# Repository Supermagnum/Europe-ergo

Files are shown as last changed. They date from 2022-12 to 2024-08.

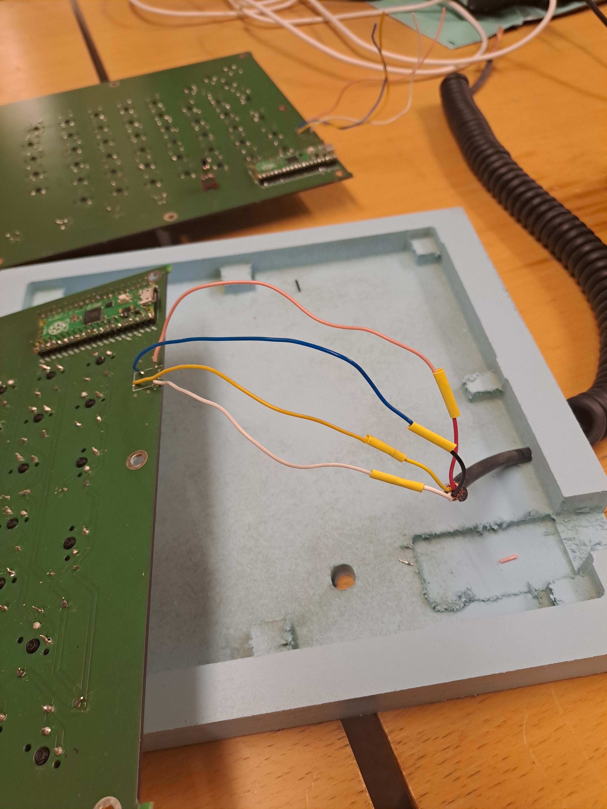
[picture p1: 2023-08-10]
prototype-build/20230810_170116.jpg

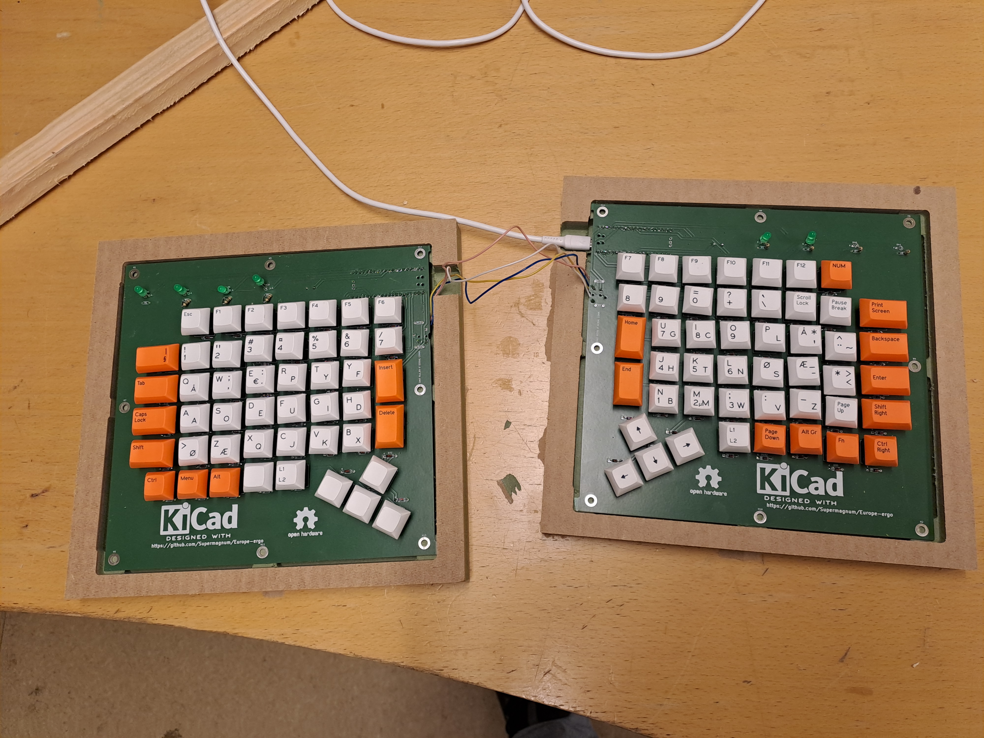
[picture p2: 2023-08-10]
prototype-build/20230720_191944.jpg

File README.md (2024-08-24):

# Europe-ergo
A 94 key ergonomic,split keyboard.
Its powered by 2X Raspberry pico and linked with two 5 pin D sub connectors.
It uses tht components.

The reset switches, 5 pin D sub connectors and raspberry pico's  goes on the reverse side of the Pcb's. 

Picture of Pcb's top side:
https://github.com/Supermagnum/Europe-ergo/blob/main/Europe-ergo-PCB/Europe-ergo-frontside.jpg

Backside:
https://github.com/Supermagnum/Europe-ergo/blob/main/Europe-ergo-PCB/Europe-ergo-backside.jpg

Layout:
https://github.com/Supermagnum/Europe-ergo/blob/main/layout.png

or:

http://www.keyboard-layout-editor.com/#/gists/50db7ea7b0832342d4c734eb985ec16b

The L1/L2 button is to change from  Norwegian QWERTY to Norwegian Dvorak.
There are relevant LEDs that lights up depending on what layer is active.

The NUM key can be used to turn the  num layer on or off.

Keycaps:
https://github.com/Supermagnum/Europe-ergo/blob/main/keycaps.jpg

prototype/"proof of concept" build pictures:
https://github.com/Supermagnum/Europe-ergo/tree/main/prototype-build

Electronic diagram:
https://github.com/Supermagnum/Europe-ergo/blob/main/Europe-ergo-PCB/schema/Europe-ergo.pdf

All mechanical blueprints as pdf files can be exported from the Freecad file.
Freecad can be found for free here:
https://www.freecadweb.org/

PWM1 to PWM 5 controls LED's ( ON/OFF) based by the active layer, and also caps lock and scroll lock active.

Those and the electrical diagram can be found here:
https://github.com/Supermagnum/Europe-ergo/blob/main/Europe-ergo-PCB/schema/Europe-ergo.pdf
The right side has identical outputs for PWM.

Cherry MX switches fit the PCB'S.

Missing from the BOM:
Keyswitch Hotswap sockets: 0305-2-15-80-47-80-10-0 or Digikey: ED90584-ND

STL files for 3D printing or milling of the boxes:
https://github.com/Supermagnum/Europe-ergo/tree/main/mechanical

Tool for aligning the switches under soldering, slips on to the PCB edge an over the switch:
https://github.com/Supermagnum/Europe-ergo/blob/main/mechanical/STL/switch-tool.stl

Panelized version:
https://github.com/Supermagnum/erope-ergo-ex

License:
https://github.com/Supermagnum/Europe-ergo/blob/main/LICENSE

 "

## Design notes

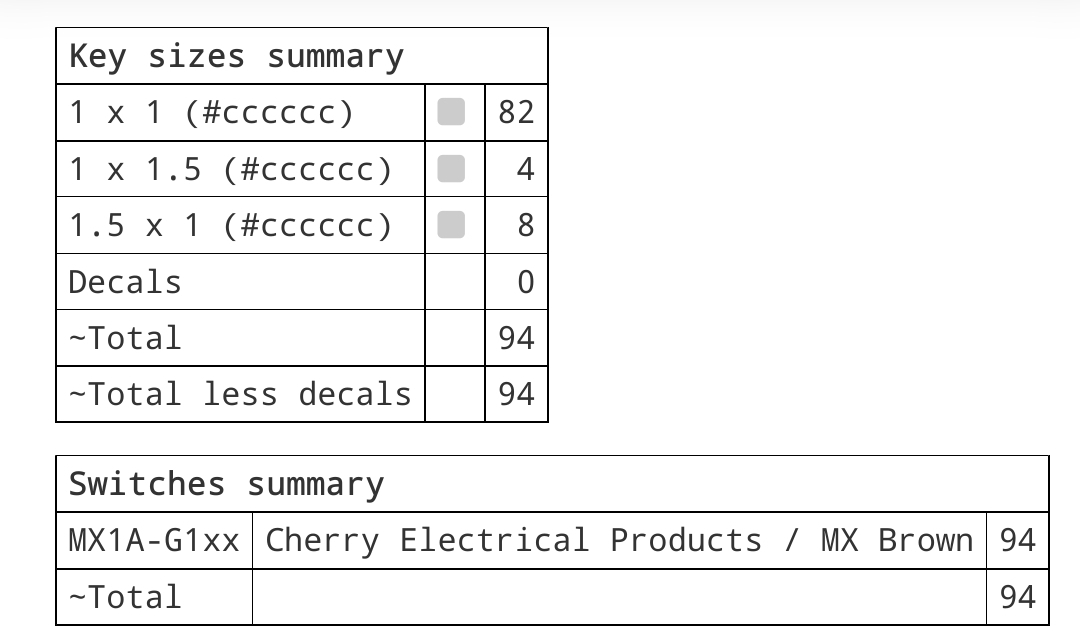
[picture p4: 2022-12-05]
keycaps.jpg

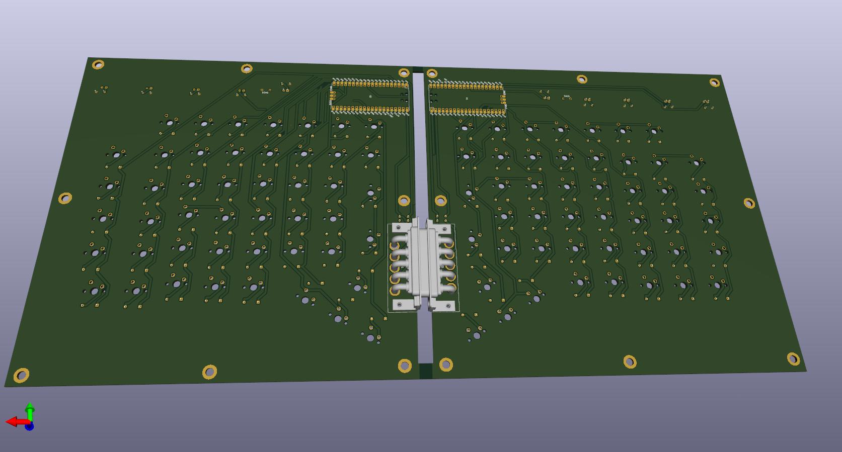
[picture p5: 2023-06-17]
Europe-ergo-PCB/Europe-ergo-backside.jpg

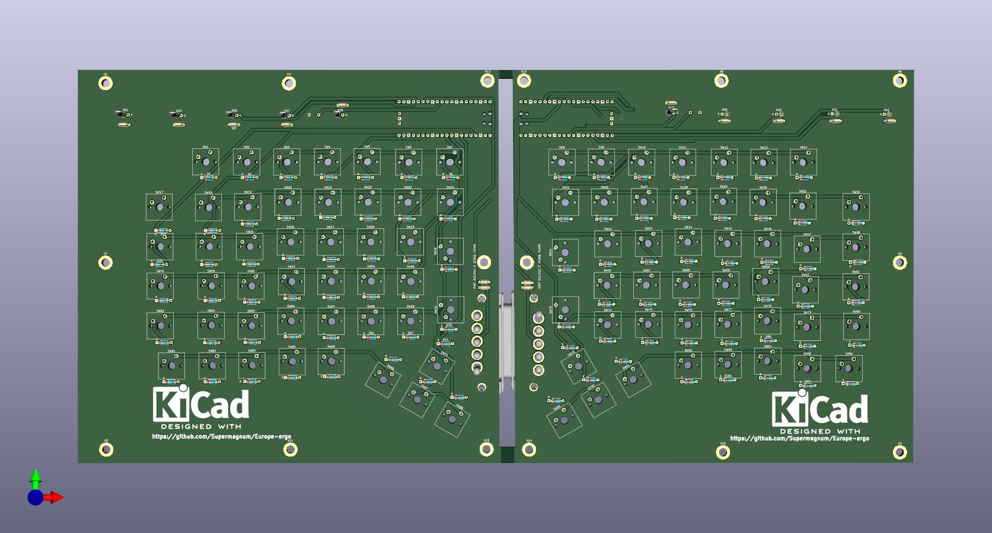
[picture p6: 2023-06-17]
Europe-ergo-PCB/Europe-ergo-frontside.jpg

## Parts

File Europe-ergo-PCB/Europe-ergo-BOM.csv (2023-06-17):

Source: | /mnt/b955457f-512b-4f44-a0f7-8e5f2b78aba2/Europe-ergo/Europe-ergo-PCB/Europe-ergo.kicad_sch
Date: | fr. 31. mars 2023 kl. 15.45 +0200
Tool: | Eeschema 7.0.1-3b83917a11~172~ubuntu22.04.1
Generator: | /usr/share/kicad/plugins/bom_csv_grouped_by_value.py
Component Count: | 234
Collated Components:
Item | Qty | Reference(s) | Value | LibPart | Footprint | Datasheet | DNP | Field4
1 | 94 | D1, D2, D3, D4, D5, D6, D7, D8, D9, D10, D11, D12, D13, D14, D15, D16, D17, D18, D19, D20, D21, D22, D23, D24, D25, D26, D27, D28, D29, D30, D33, D34, D35, D44, D45, D46, D47, D48, D49, D50, D51, D52, D53, D54, D55, D56, D57, D58, D59, D60, D61, D62, D63, D64, D65, D66, D67, D68, D69, D70, D71, D72, D73, D74, D75, D76, D77, D78, D79, D80, D81, D82, D83, D84, D85, D86, D87, D88, D89, D90, D91, D92, D93, D94, D95, D96, D97, D98, D99, D100, D101, D102, D103, D104 | 1N4148 | Diode:1N4148 | Diode_THT:D_DO-35_SOD27_P7.62mm_Horizontal | https://assets.nexperia.com/documents/data-sheet/1N4148_1N4448.pdf
2 | 6 | D31, D32, D36, D37, D38, D43 | LTL-4233 | Device:LED | Diode_THT:D_A-405_P2.54mm_Vertical_AnodeUp | ~
3 | 4 | D39, D40, D41, D42 | LTL-4233 | Device:LED | Diode_THT:D_DO-34_SOD68_P2.54mm_Vertical_KathodeUp | ~
4 | 16 | H1, H2, H3, H4, H5, H6, H7, H8, H9, H10, H11, H12, H13, H14, H15, H16 | MountingHole_Pad | Mechanical:MountingHole_Pad | MountingHole:MountingHole_4.3mm_M4_DIN965_Pad | ~
5 | 2 | J1, J2 | SJ-435107 | Connector: CONN D-SUB PLUG 5POS R/A SLDR | NOR1213-ND | ~
6 | 10 | R1, R2, R3, R4, R5, R6, R7, R8, R9, R10 | 330 | Device:R | Resistor_THT:R_Axial_DIN0204_L3.6mm_D1.6mm_P5.08mm_Horizontal | ~
7 | 4 | R11, R12, R13, R14 | 4.7K | Device:R | Resistor_THT:R_Axial_DIN0204_L3.6mm_D1.6mm_P5.08mm_Horizontal | ~
8 | 41 | SW1, SW2, SW3, SW4, SW5, SW6, SW7, SW18, SW19, SW20, SW21, SW22, SW23, SW24, SW34, SW35, SW36, SW37, SW38, SW39, SW50, SW51, SW52, SW53, SW54, SW55, SW64, SW65, SW66, SW67, SW68, SW69, SW71, SW81, SW82, SW83, SW84, SW85, SW86, SW87, SW88 | MX1A-G1NN | pcb-flat-left-rescue:MX-NO-LED-keyboard2-pcb-flat-right-rescue | Button_Switch_Keyboard:SW_Cherry_MX_1.00u_PCB |  |  | arrow-up
9 | 41 | SW8, SW9, SW10, SW11, SW12, SW13, SW14, SW25, SW26, SW27, SW28, SW29, SW30, SW31, SW42, SW43, SW44, SW45, SW46, SW47, SW56, SW57, SW58, SW59, SW60, SW61, SW72, SW74, SW75, SW76, SW77, SW78, SW79, SW89, SW90, SW91, SW92, SW93, SW94, SW95, SW96 | MX1A-G1NN | pcb-flat-right-rescue:MX-NO-LED-keyboard2 | Button_Switch_Keyboard:SW_Cherry_MX_1.00u_PCB |  |  | arrow-up
10 | 2 | SW15, SW16 | 800SP9B6M2RE | Switch:SW_Push | switch:switch_P5.08mm | ~
11 | 6 | SW17, SW33, SW40, SW49, SW63, SW70 | MX1A-G1NN | pcb-flat-left-rescue:MX-NO-LED-keyboard2-pcb-flat-right-rescue | Button_Switch_Keyboard:SW_Cherry_MX_1.50u_PCB
12 | 6 | SW32, SW41, SW48, SW62, SW73, SW80 | MX1A-G1NN | pcb-flat-right-rescue:MX-NO-LED-keyboard2 | Button_Switch_Keyboard:SW_Cherry_MX_1.50u_PCB
13 | 2 | U1, U2 | SC0915 | MCU_RaspberryPi_and_Boards:Pico | MCU_RaspberryPi_and_Boards:RPi_Pico_SMD_TH

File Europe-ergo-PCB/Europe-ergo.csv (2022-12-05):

Source: | /home/haaken/98keys-ergo.git/trunk/98keys-split-pcb/98keys-split-pcb.kicad_sch
Date: | lø. 03. des. 2022 kl. 18.18 +0100
Tool: | Eeschema 6.0.9-8da3e8f707~117~ubuntu20.04.1
Generator: | /usr/share/kicad/plugins/bom_csv_grouped_by_value_with_fp.py
Component Count: | 230
Ref | Qnty | Value | Cmp name | Footprint | Description | Vendor
D1, D2, D3, D4, D5, D6, D7, D8, D9, D10, D11, D12, D13, D14, D15, D16, D17, D18, D19, D20, D21, D22, D23, D24, D25, D26, D27, D28, D29, D30, D31, D32, D33, D34, D35, D36, D37, D38, D39, D40, D41, D42, D43, D44, D45, D46, D47, D56, D57, D58, D59, D60, D61, D62, D63, D64, D65, D66, D67, D68, D69, D70, D71, D72, D73, D74, D75, D76, D77, D78, D79, D80, D81, D82, D83, D84, D85, D86, D87, D88, D89, D90, D91, D92, D93, D94, D95, D96, D97, D98, D99, D100, D101, D102, | 94 | 1N4148 | 1N4148 | Diode_THT:D_DO-35_SOD27_P7.62mm_Horizontal | 100V 0.15A standard switching diode, DO-35
D48, D49, D50, D51, | 4 | LED | LED | Diode_THT:D_DO-34_SOD68_P2.54mm_Vertical_KathodeUp | Light emitting diode
D52, D53, D54, D55, | 4 | LTL-4233 | LED | Diode_THT:D_A-405_P2.54mm_Vertical_AnodeUp | Light emitting diode
H1, H2, H3, H4, H5, H6, H7, H8, H9, H10, H11, H12, H13, H14, H15, H16, | 16 | MountingHole_Pad | MountingHole_Pad | MountingHole:MountingHole_4.3mm_M4_DIN965_Pad | Mounting Hole with connection
J1, | 1 | Conn_01x04_Male/I2C | Conn_01x04_Male | Connector_Audio:Jack_3.5mm_CUI_SJ1-43514_Horizontal | Generic connector, single row, 01x04, script generated (kicad-library-utils/schlib/autogen/connector/)
J2, | 1 | Conn_01x04_Male | Conn_01x04_Male | Connector_Audio:Jack_3.5mm_CUI_SJ1-43514_Horizontal | Generic connector, single row, 01x04, script generated (kicad-library-utils/schlib/autogen/connector/)
R1, R2, R4, R6, R7, R8, R10, R12, | 8 | 330 | R | Resistor_THT:R_Axial_DIN0204_L3.6mm_D1.6mm_P5.08mm_Horizontal | Resistor
R3, R5, R9, R11, | 4 | 4.7K | R | Resistor_THT:R_Axial_DIN0204_L3.6mm_D1.6mm_P5.08mm_Horizontal | Resistor
SW1, SW6, SW7, SW8, SW9, SW10, SW11, SW12, SW13, SW14, SW15, SW16, SW17, SW18, SW19, SW20, SW21, SW22, SW23, SW24, SW25, SW26, SW27, SW28, SW29, SW30, SW31, SW32, SW33, SW34, SW35, SW36, SW37, SW38, SW39, SW40, SW41, SW42, SW45, SW46, SW47, SW50, SW51, SW52, SW55, SW56, SW57, SW58, SW59, SW60, SW61, SW62, SW63, SW64, SW65, SW66, SW67, SW68, SW69, SW70, SW71, SW72, SW73, SW74, SW75, SW76, SW77, SW78, SW79, SW80, SW81, SW82, SW83, SW84, SW85, SW86, SW87, SW88, SW89, SW90, SW92, SW96, | 82 | MX-NO-LED | MX-NO-LED-keyboard2-pcb-flat-right-rescue | Button_Switch_Keyboard:SW_Cherry_MX_1.00u_PCB
SW2, SW3, SW4, SW5, SW43, SW44, SW53, SW54, SW91, SW93, SW94, SW95, | 12 | MX-NO-LED | MX-NO-LED-keyboard2-pcb-flat-right-rescue | Button_Switch_Keyboard:SW_Cherry_MX_1.50u_PCB
SW48, SW49, | 2 | SW_Push | SW_Push | switch:switch_P5.08mm | Push button switch, generic, two pins
U1, U2, | 2 | Pico | Pico | MCU_RaspberryPi_and_Boards:RPi_Pico_SMD_TH

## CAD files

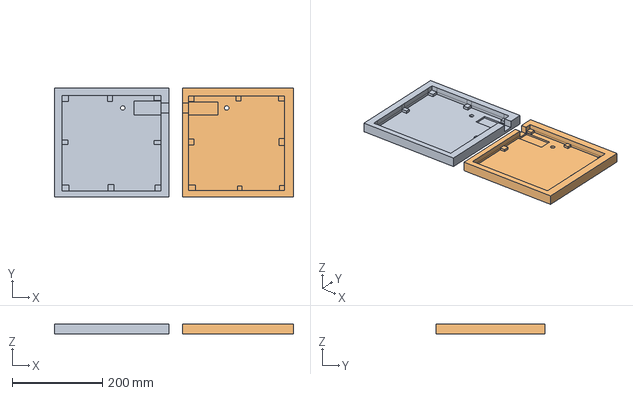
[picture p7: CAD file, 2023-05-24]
mechanical/Europe-ergo.FCStd
529.6 x 242.0 x 22.0 mm
Left

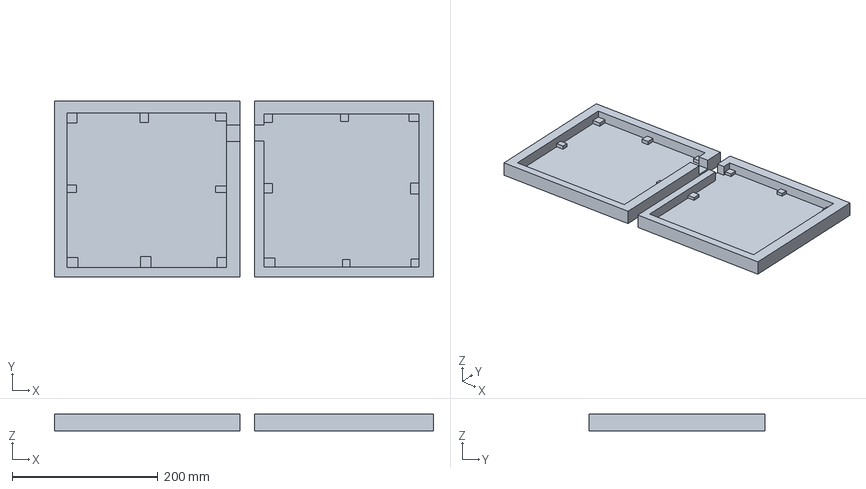
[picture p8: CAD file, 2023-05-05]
mechanical/Europe-ergo-comb.3mf
519.6 x 242.0 x 23.0 mm

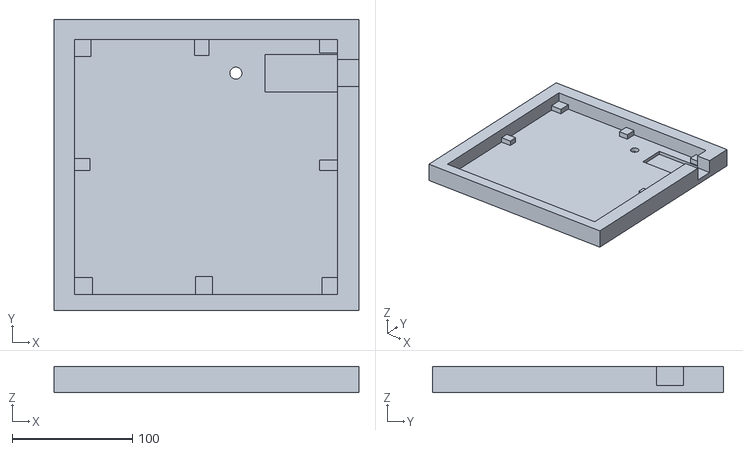
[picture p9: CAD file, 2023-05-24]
mechanical/STL/Europe-ergo-left.stl
254.0 x 242.0 x 22.0

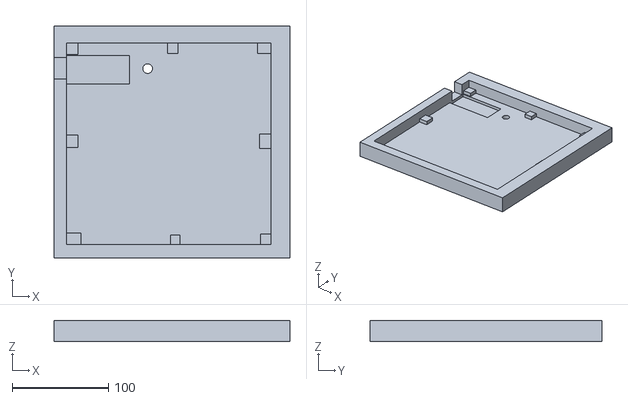
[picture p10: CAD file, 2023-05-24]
mechanical/STL/Europe-ergo-right.stl
245.6 x 241.5 x 22.0

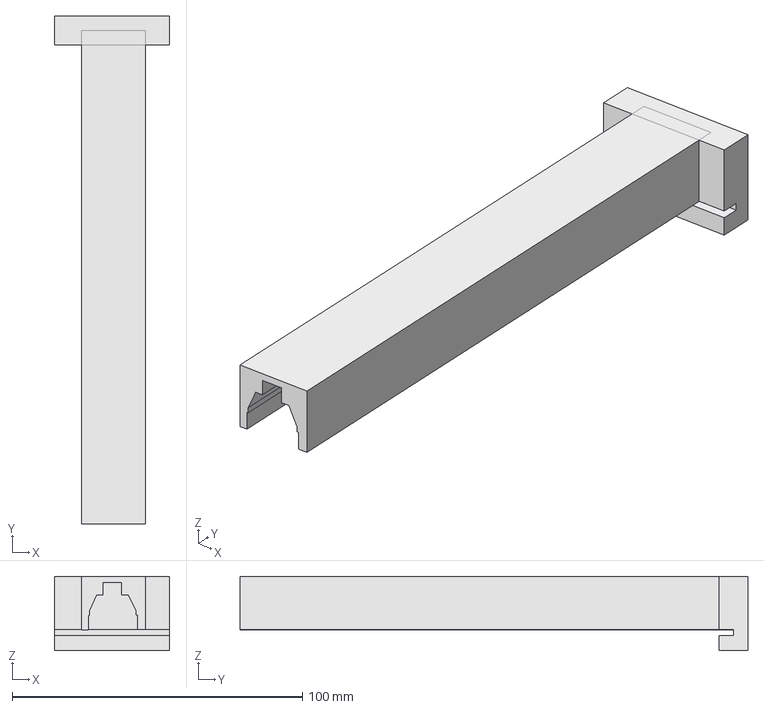
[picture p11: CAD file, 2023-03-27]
mechanical/switch-tool.FCStd
39.7 x 175.0 x 25.5 mm

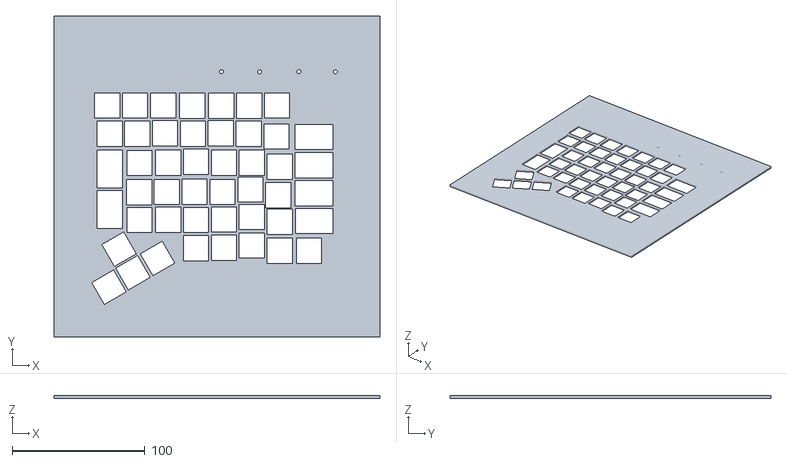
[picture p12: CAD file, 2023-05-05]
mechanical/STL/Europe-ergo-lid.stl
245.6 x 241.5 x 2.00

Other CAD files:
Europe-ergo.dxf
mechanical/STL/Europe-ergo-boxes.stl
mechanical/Europe-ergo.dxf
mechanical/STL/switch-tool.stl

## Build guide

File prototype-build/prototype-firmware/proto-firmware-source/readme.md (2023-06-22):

# europe_ergo

europe_ergo

*A short description of the keyboard/project*

* Keyboard Maintainer: [Supermagnum](https://github.com/Supermagnum)
* Hardware Supported: *The PCBs, controllers supported*
* Hardware Availability: *Links to where you can find this hardware*

Make example for this keyboard (after setting up your build environment):

    make europe_ergo:default

Flashing example for this keyboard:

    make europe_ergo:default:flash

See the [build environment setup](https://docs.qmk.fm/#/getting_started_build_tools) and the [make instructions](https://docs.qmk.fm/#/getting_started_make_guide) for more information. Brand new to QMK? Start with our [Complete Newbs Guide](https://docs.qmk.fm/#/newbs).

## Bootloader

Enter the bootloader in 3 ways:

* **Bootmagic reset**: Hold down the key at (0,0) in the matrix (usually the top left key or Escape) and plug in the keyboard
* **Physical reset button**: Briefly press the button on the back of the PCB - some may have pads you must short instead
* **Keycode in layout**: Press the key mapped to `QK_BOOT` if it is available

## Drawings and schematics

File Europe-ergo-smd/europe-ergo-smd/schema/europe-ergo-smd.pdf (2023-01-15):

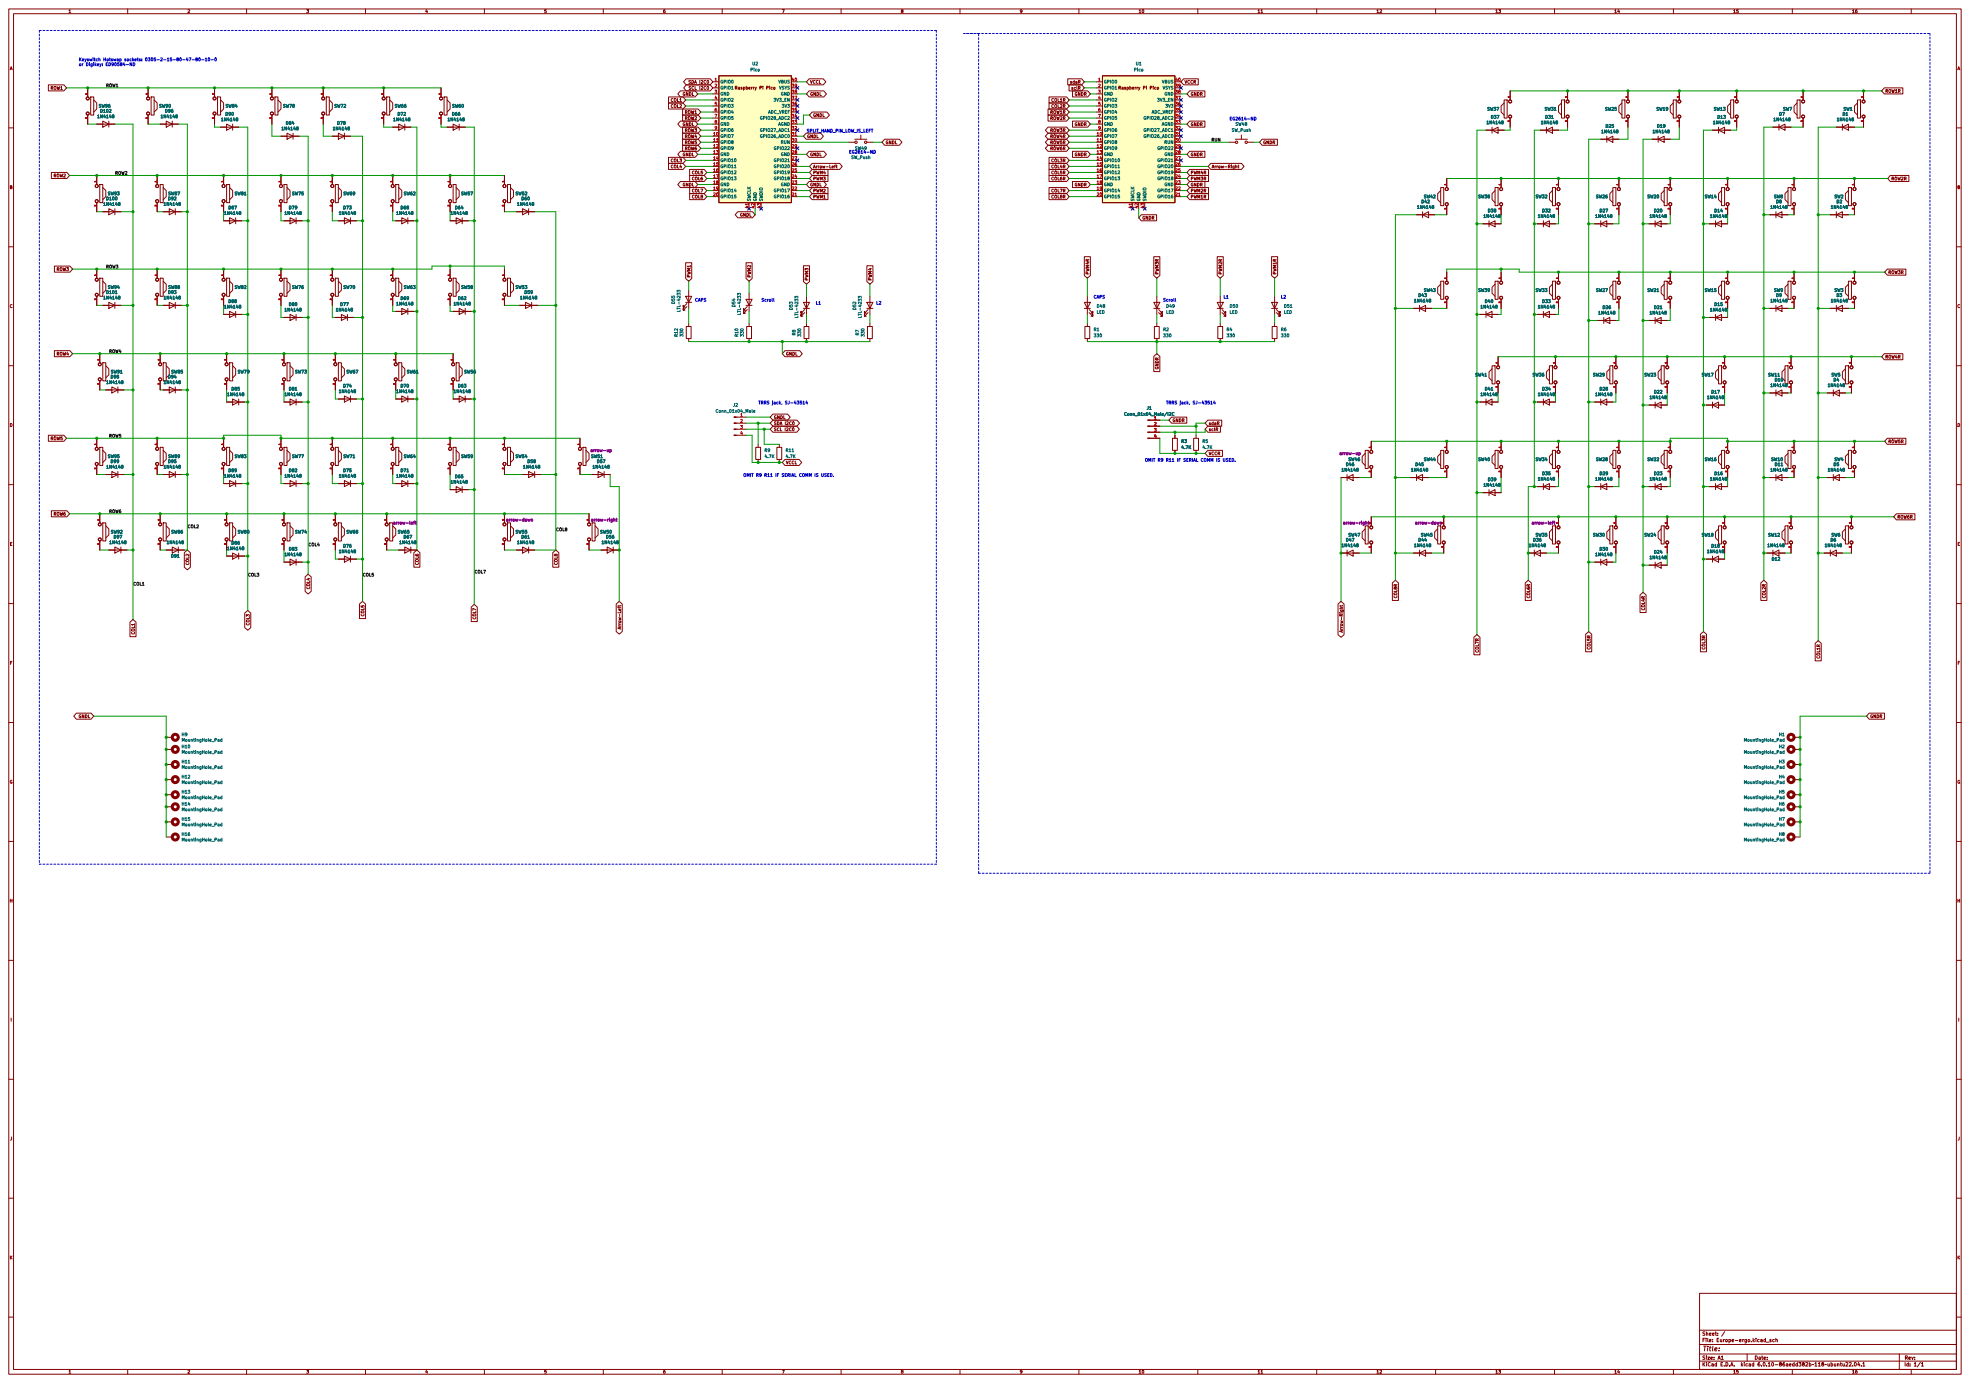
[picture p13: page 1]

File: Europe-ergo.kicad_sch Sheet: /

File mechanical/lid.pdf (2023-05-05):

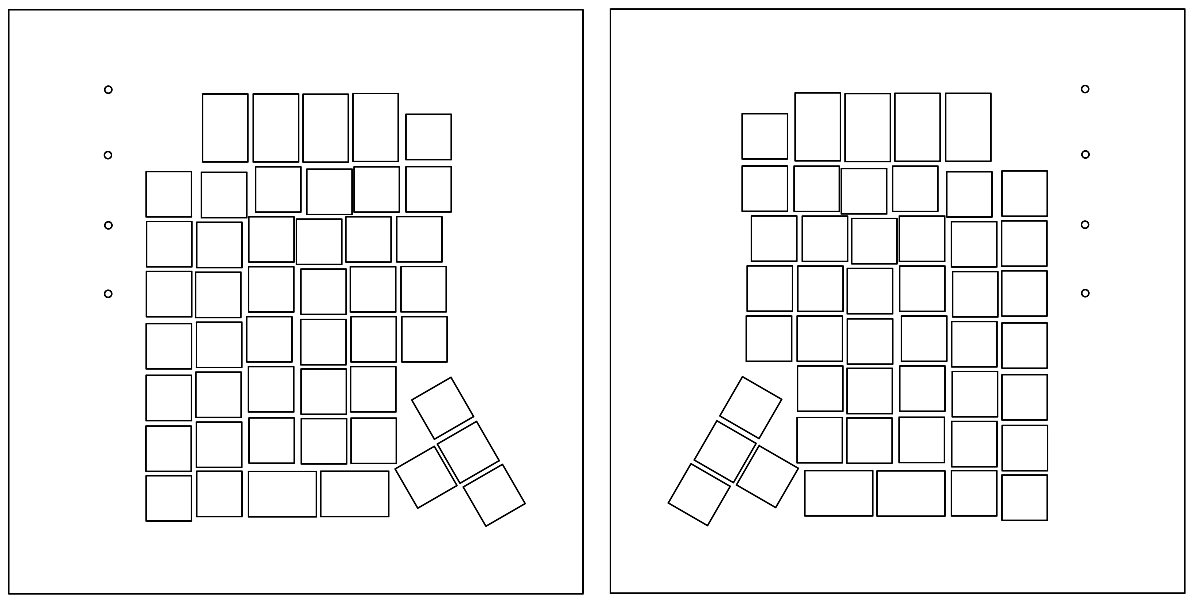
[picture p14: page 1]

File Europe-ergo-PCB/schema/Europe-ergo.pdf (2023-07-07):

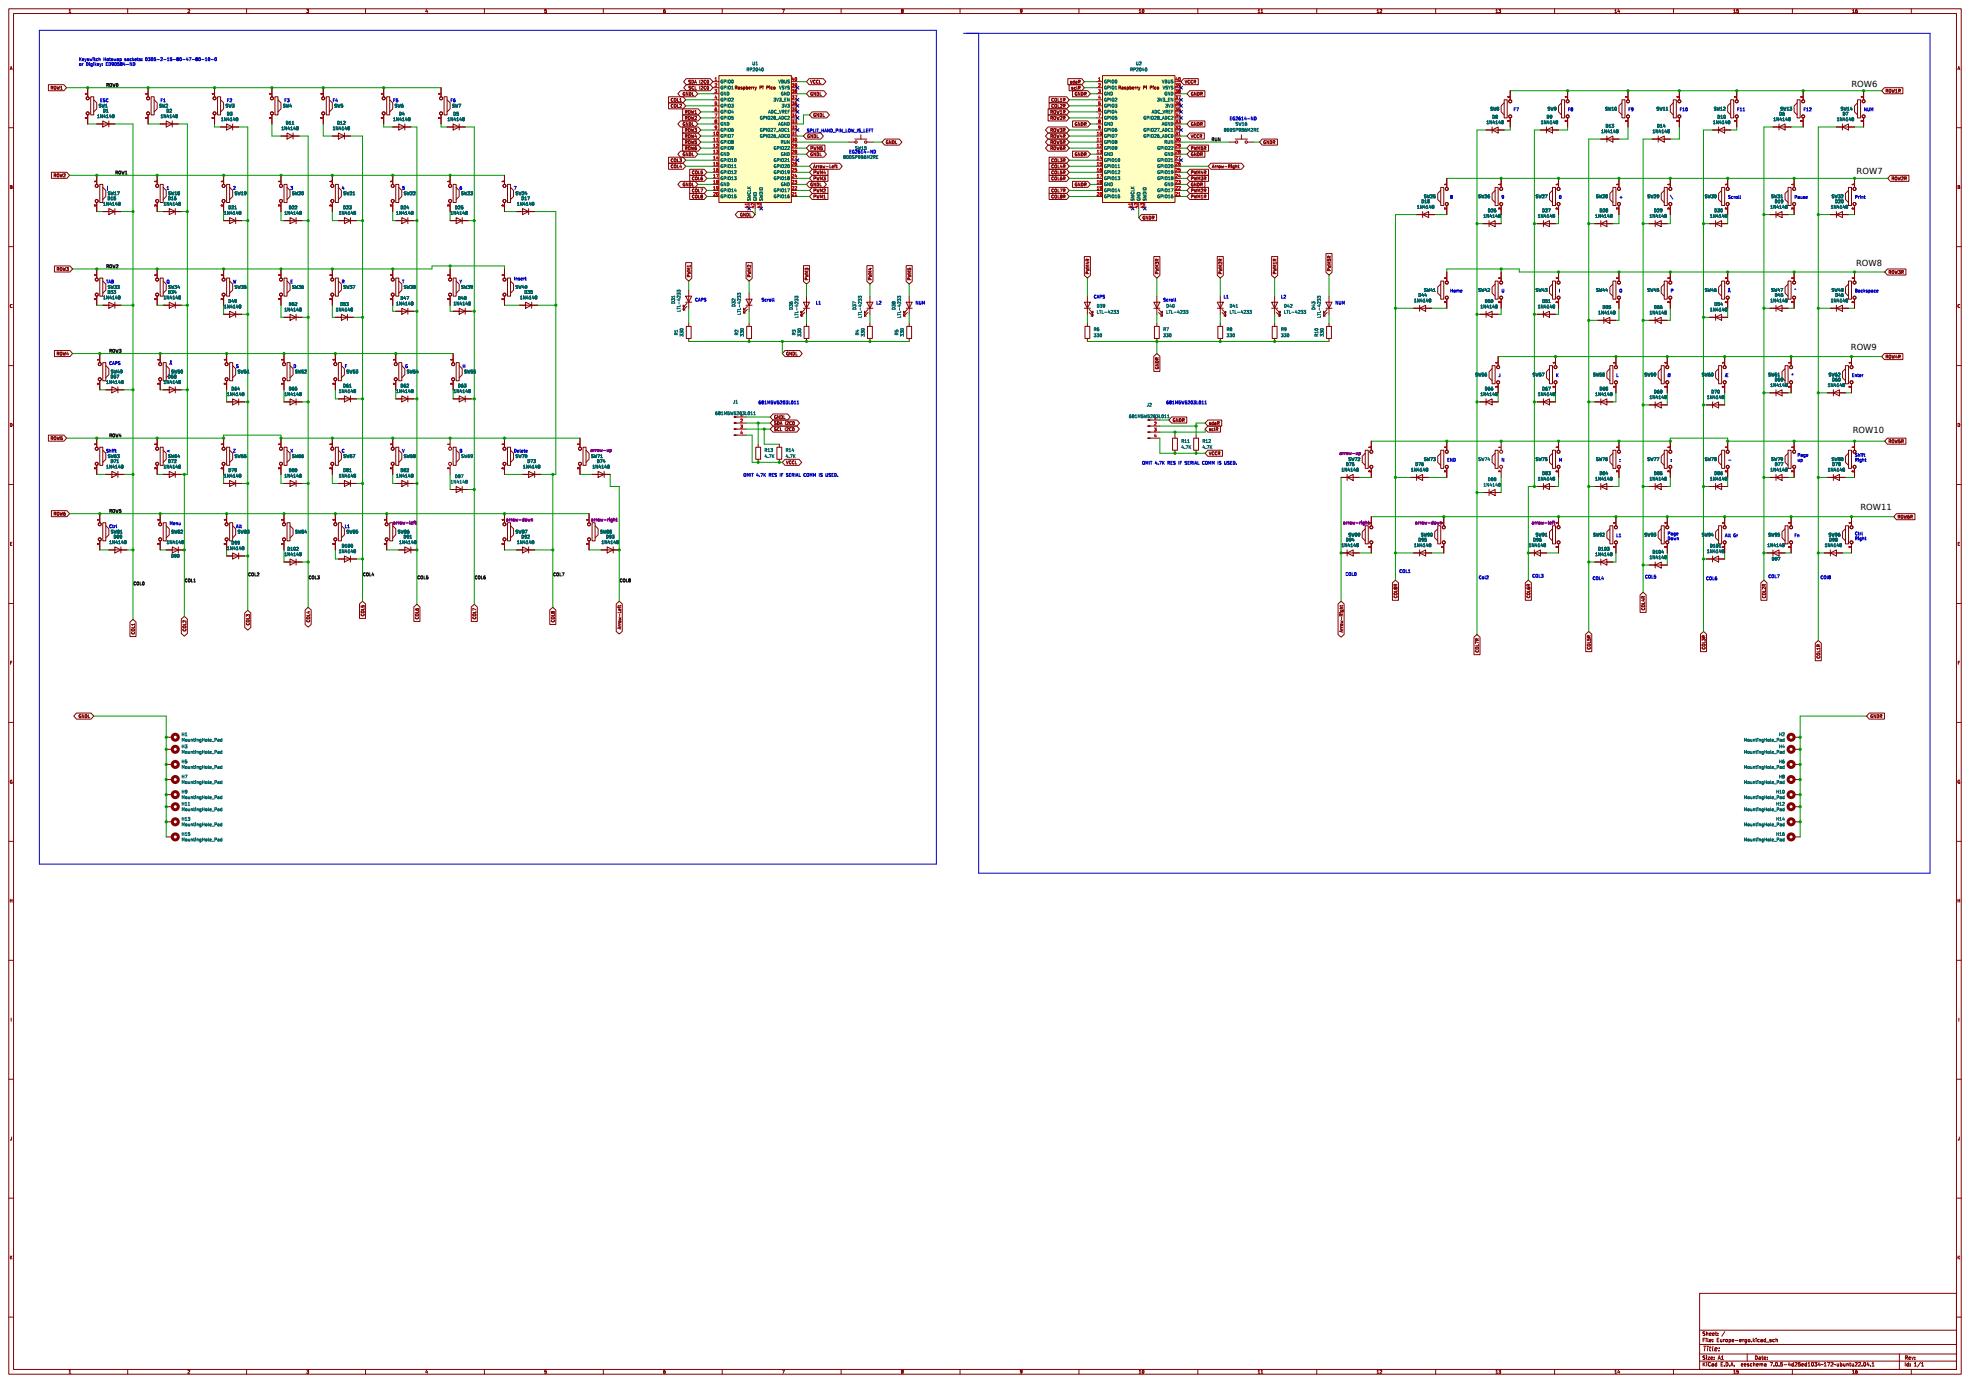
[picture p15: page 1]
ROW6; ROW7; ROW8; ROW9; ROW10; ROW11

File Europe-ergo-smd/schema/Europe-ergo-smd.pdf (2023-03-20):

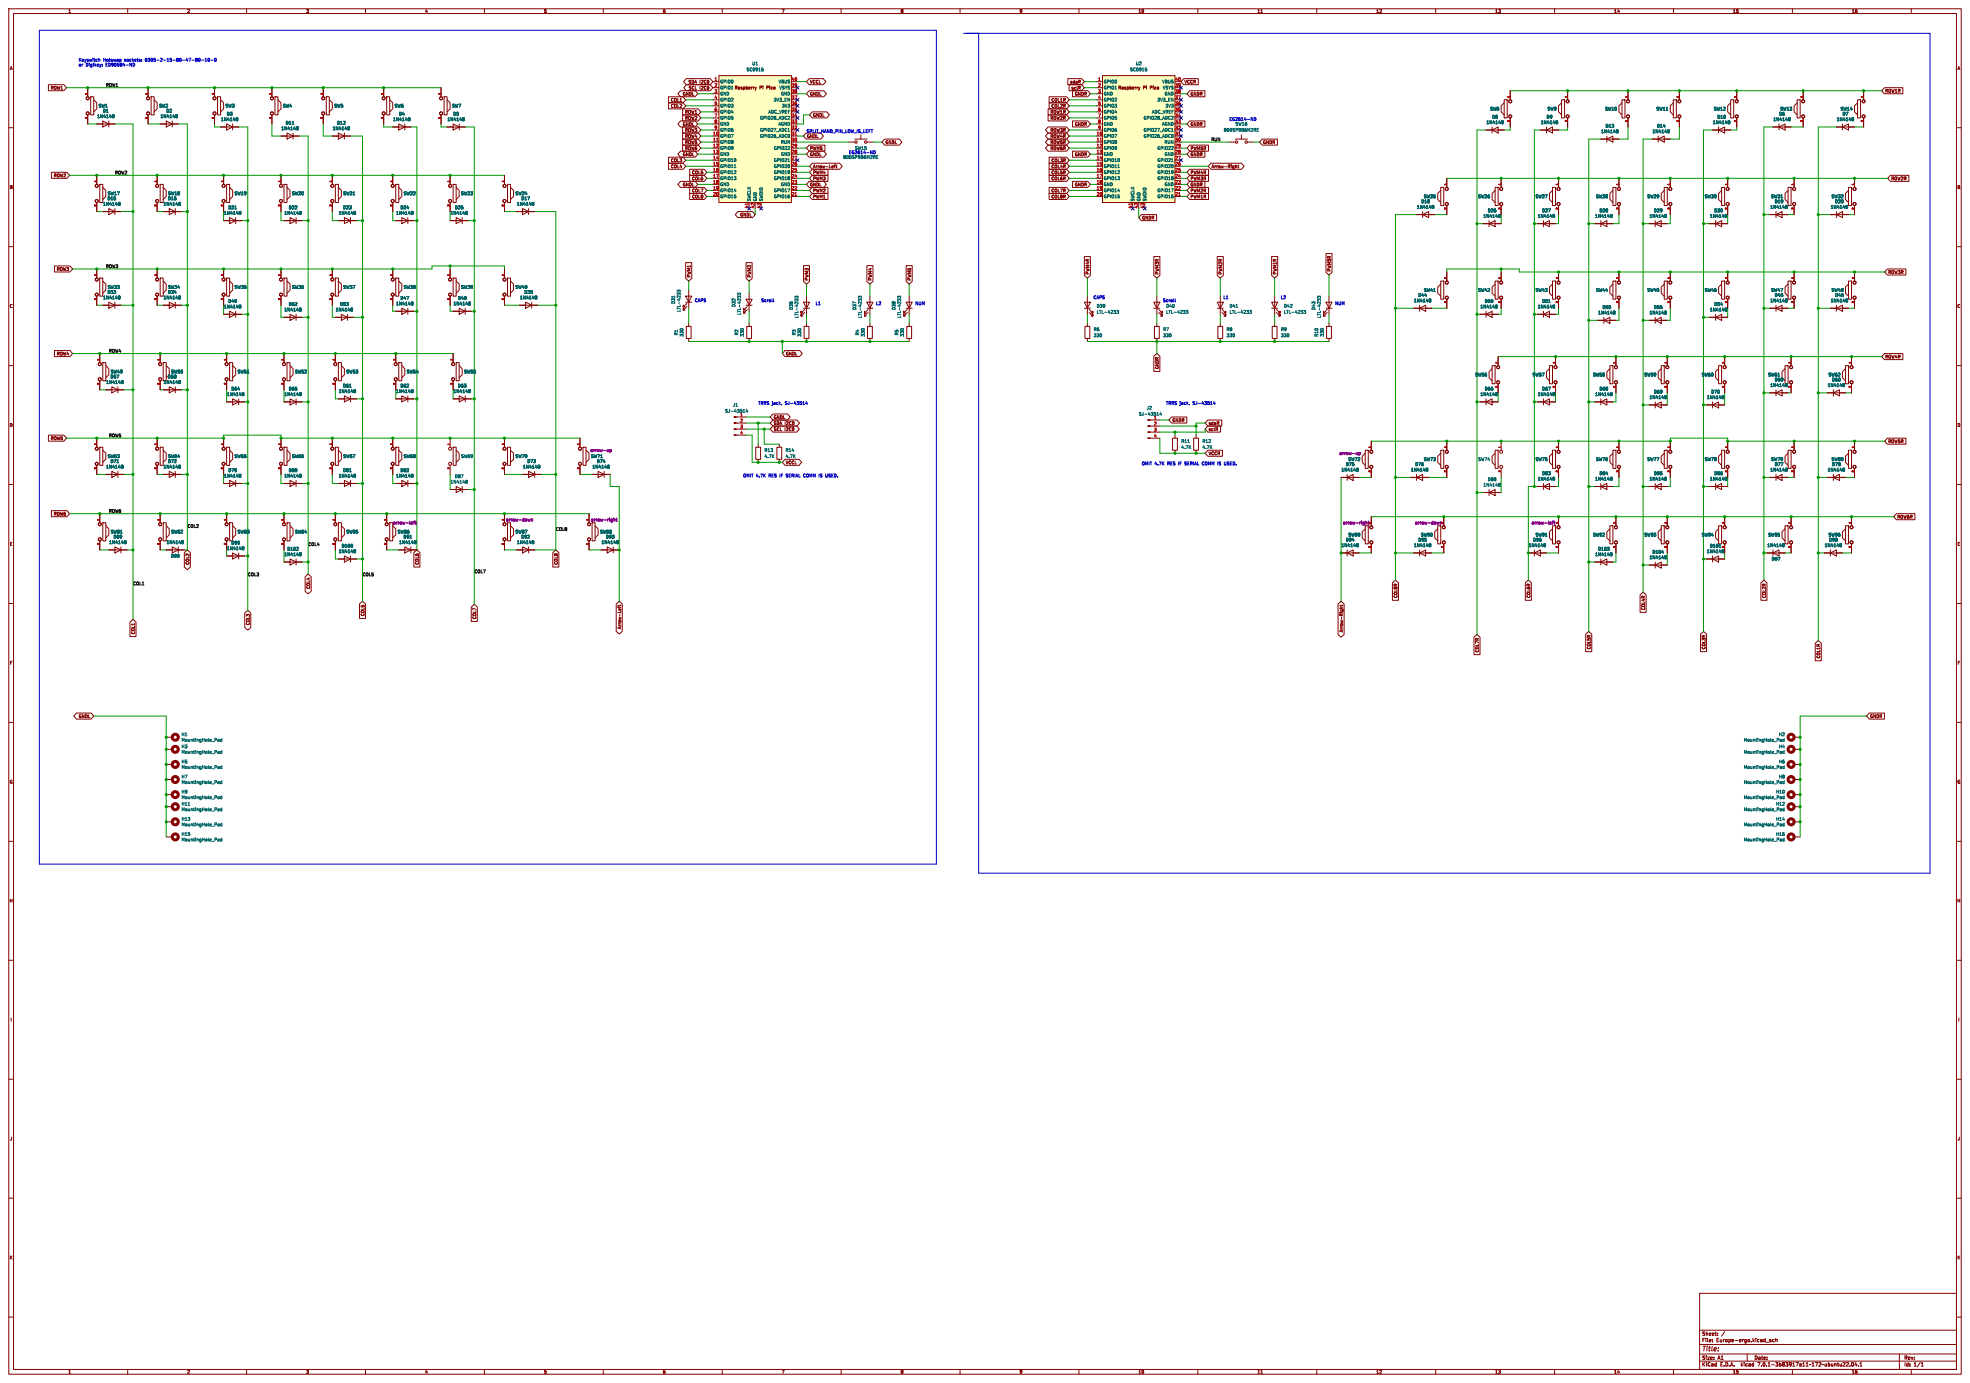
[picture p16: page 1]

EG2614-ND OMIT 4.7K RES IF SERIAL COMM IS USED.

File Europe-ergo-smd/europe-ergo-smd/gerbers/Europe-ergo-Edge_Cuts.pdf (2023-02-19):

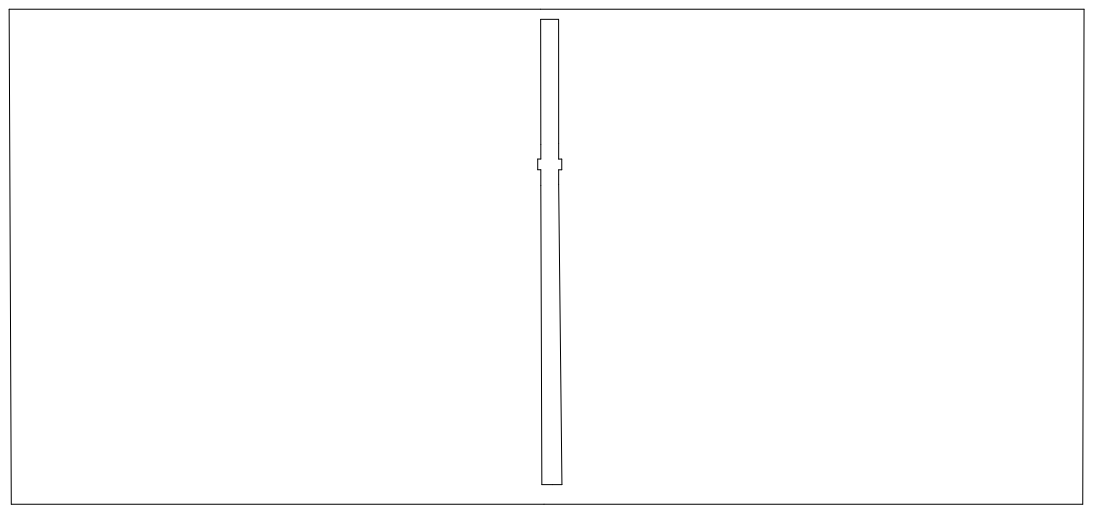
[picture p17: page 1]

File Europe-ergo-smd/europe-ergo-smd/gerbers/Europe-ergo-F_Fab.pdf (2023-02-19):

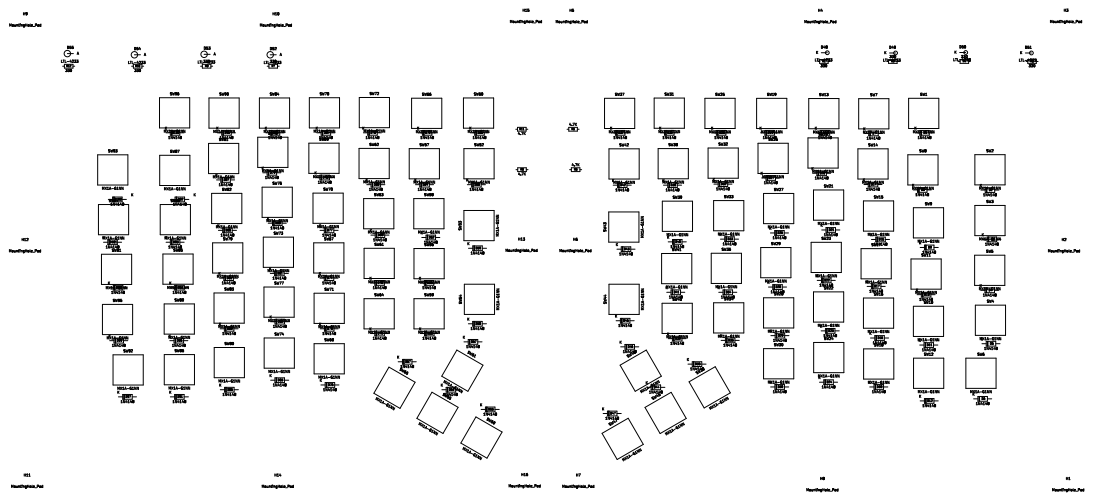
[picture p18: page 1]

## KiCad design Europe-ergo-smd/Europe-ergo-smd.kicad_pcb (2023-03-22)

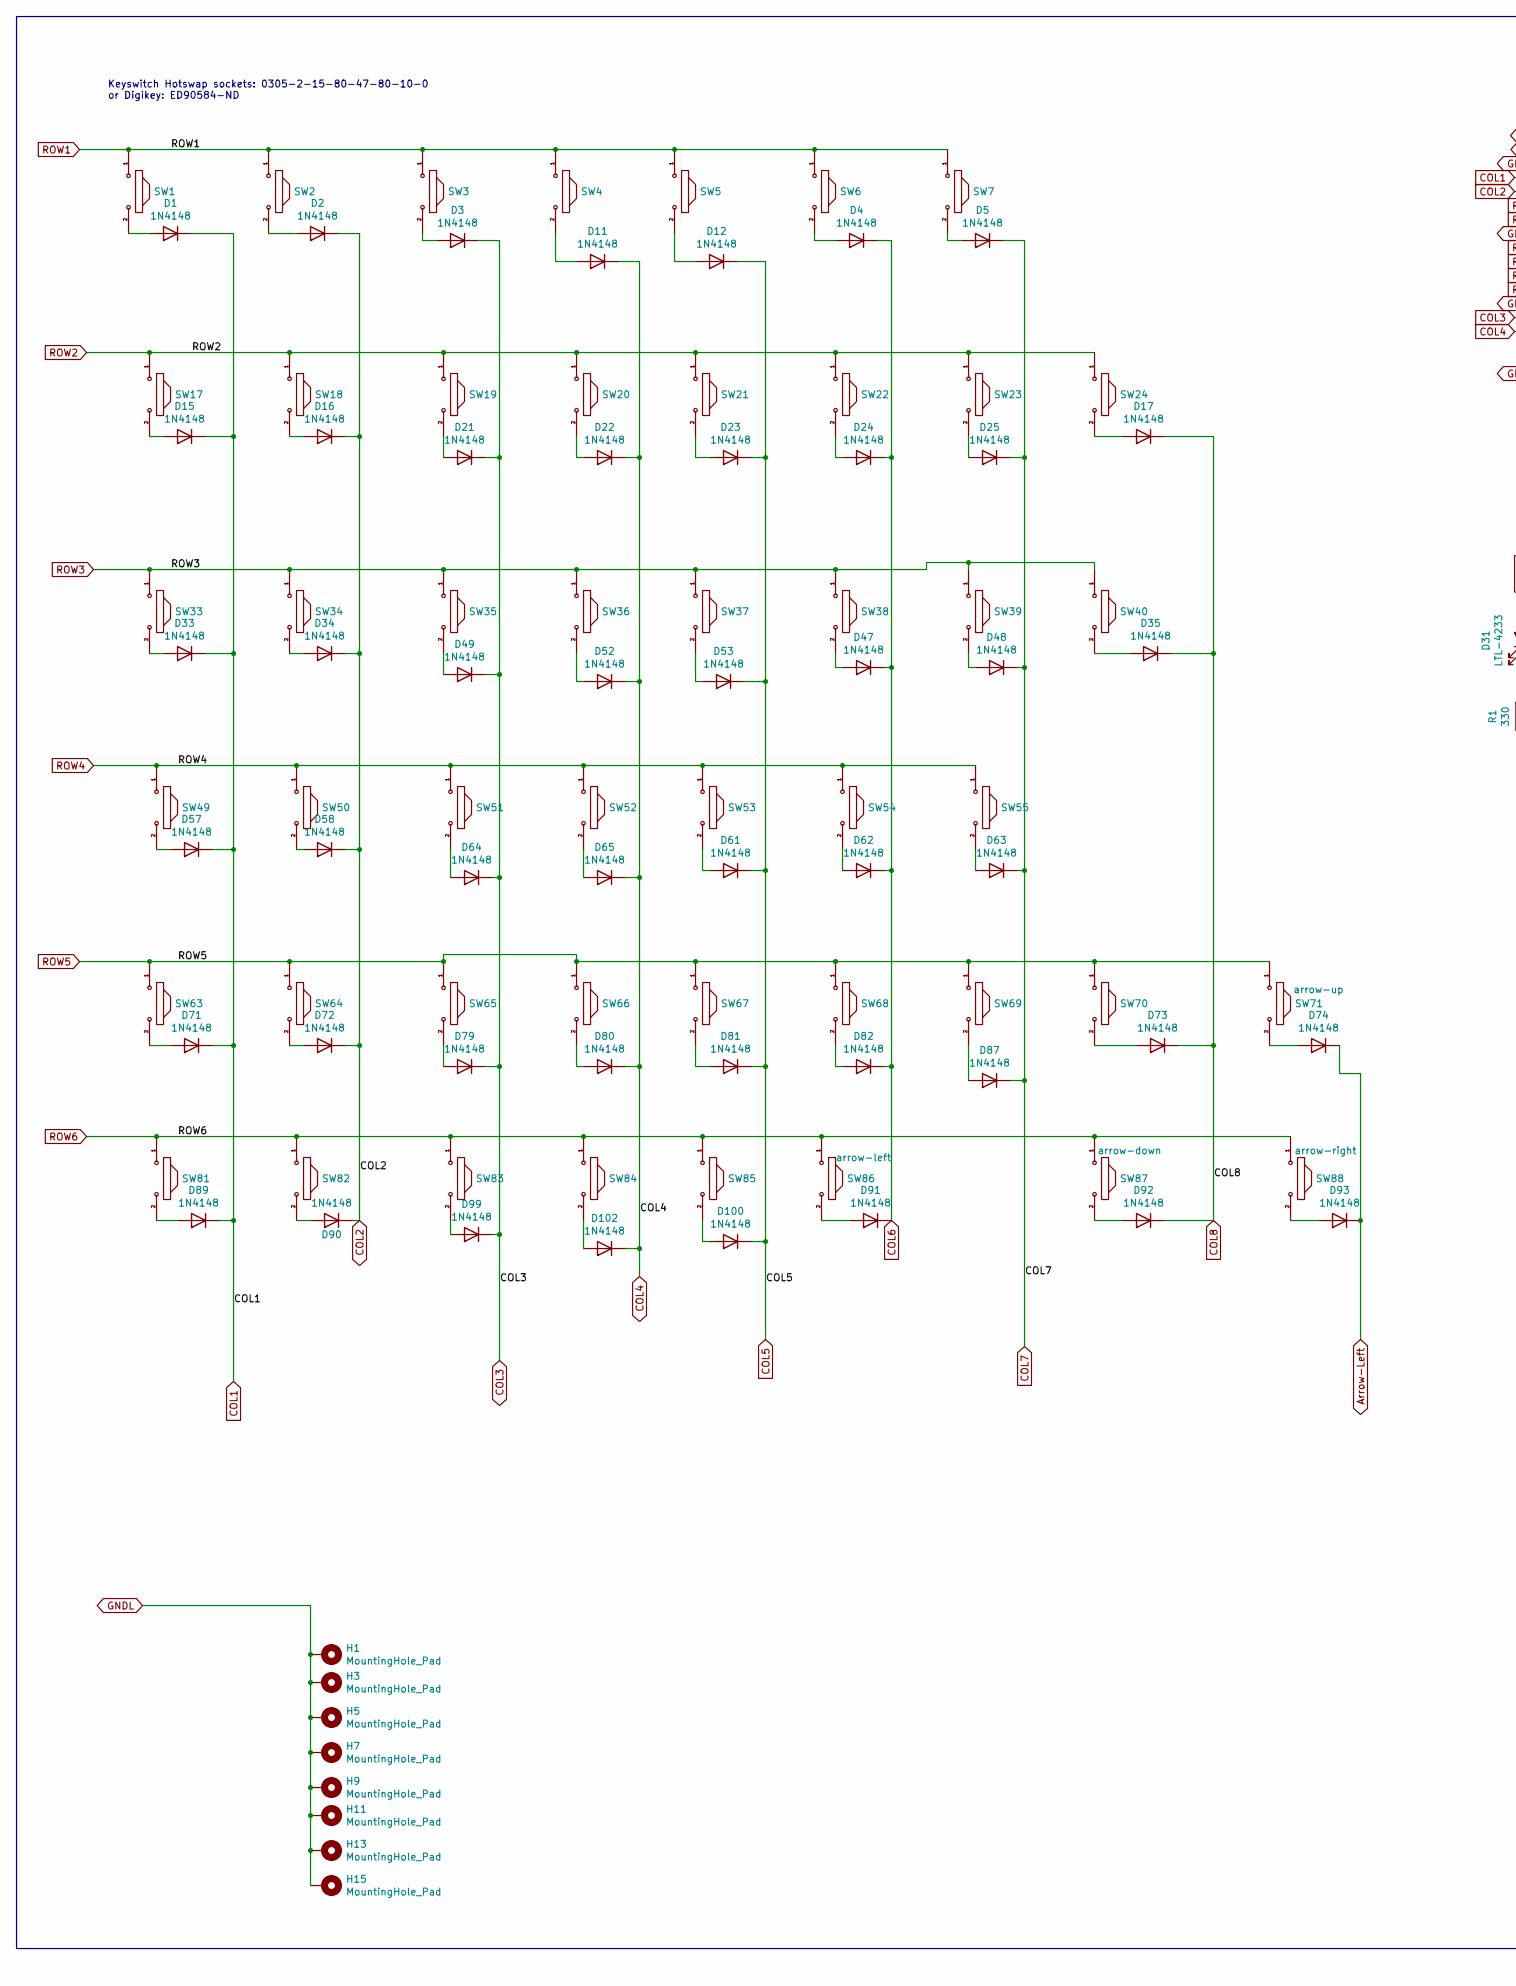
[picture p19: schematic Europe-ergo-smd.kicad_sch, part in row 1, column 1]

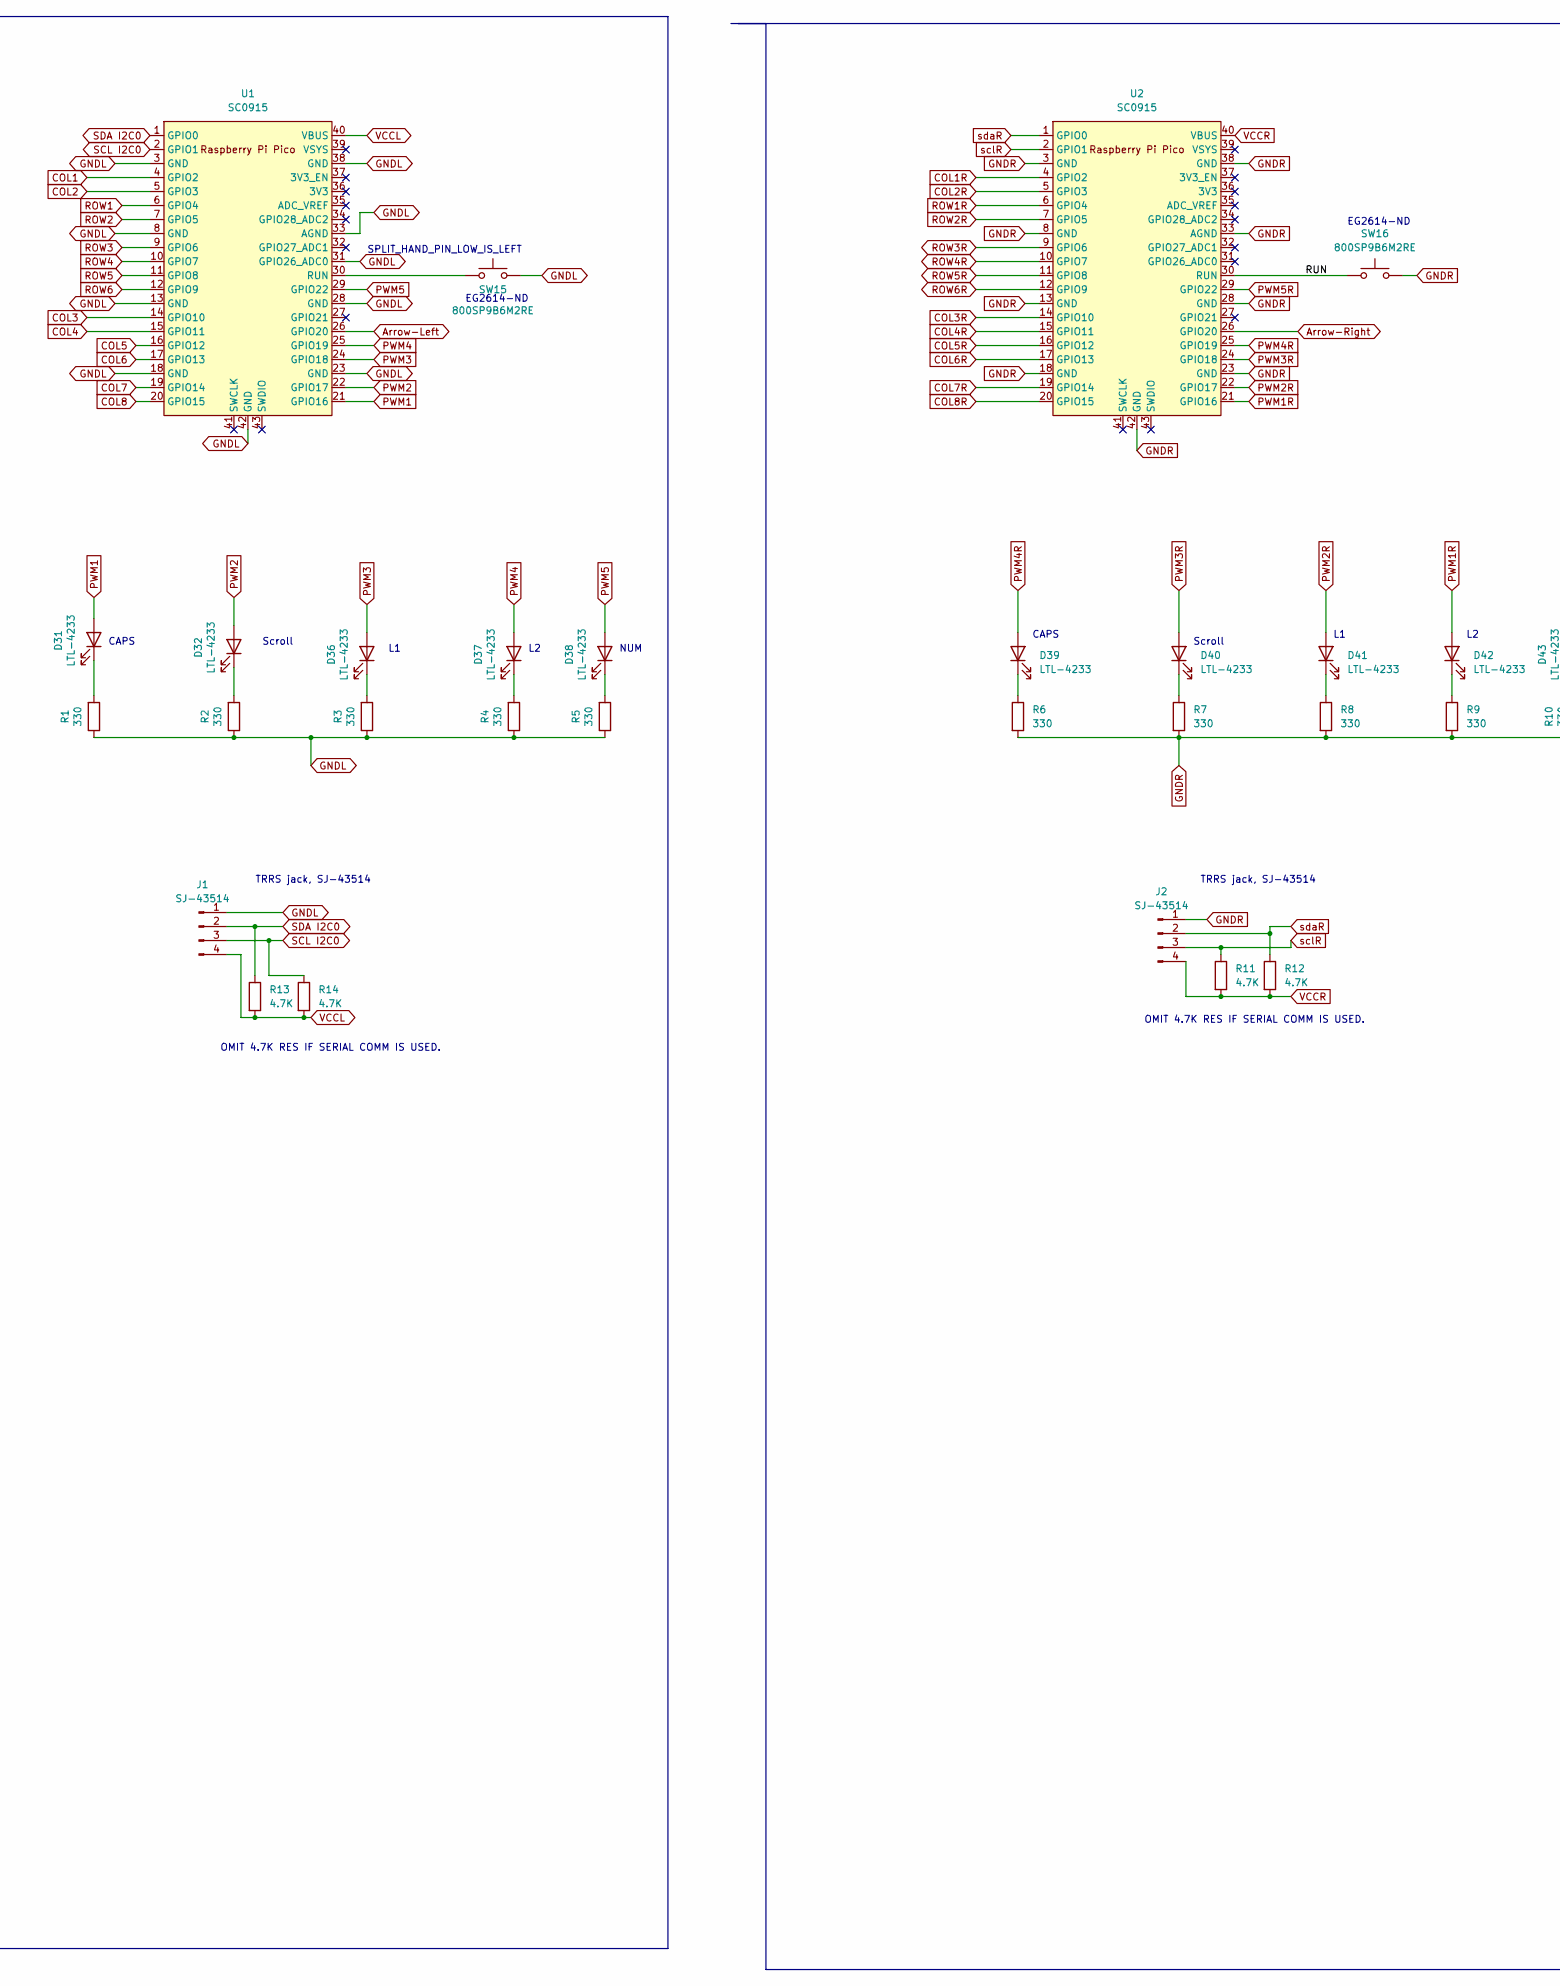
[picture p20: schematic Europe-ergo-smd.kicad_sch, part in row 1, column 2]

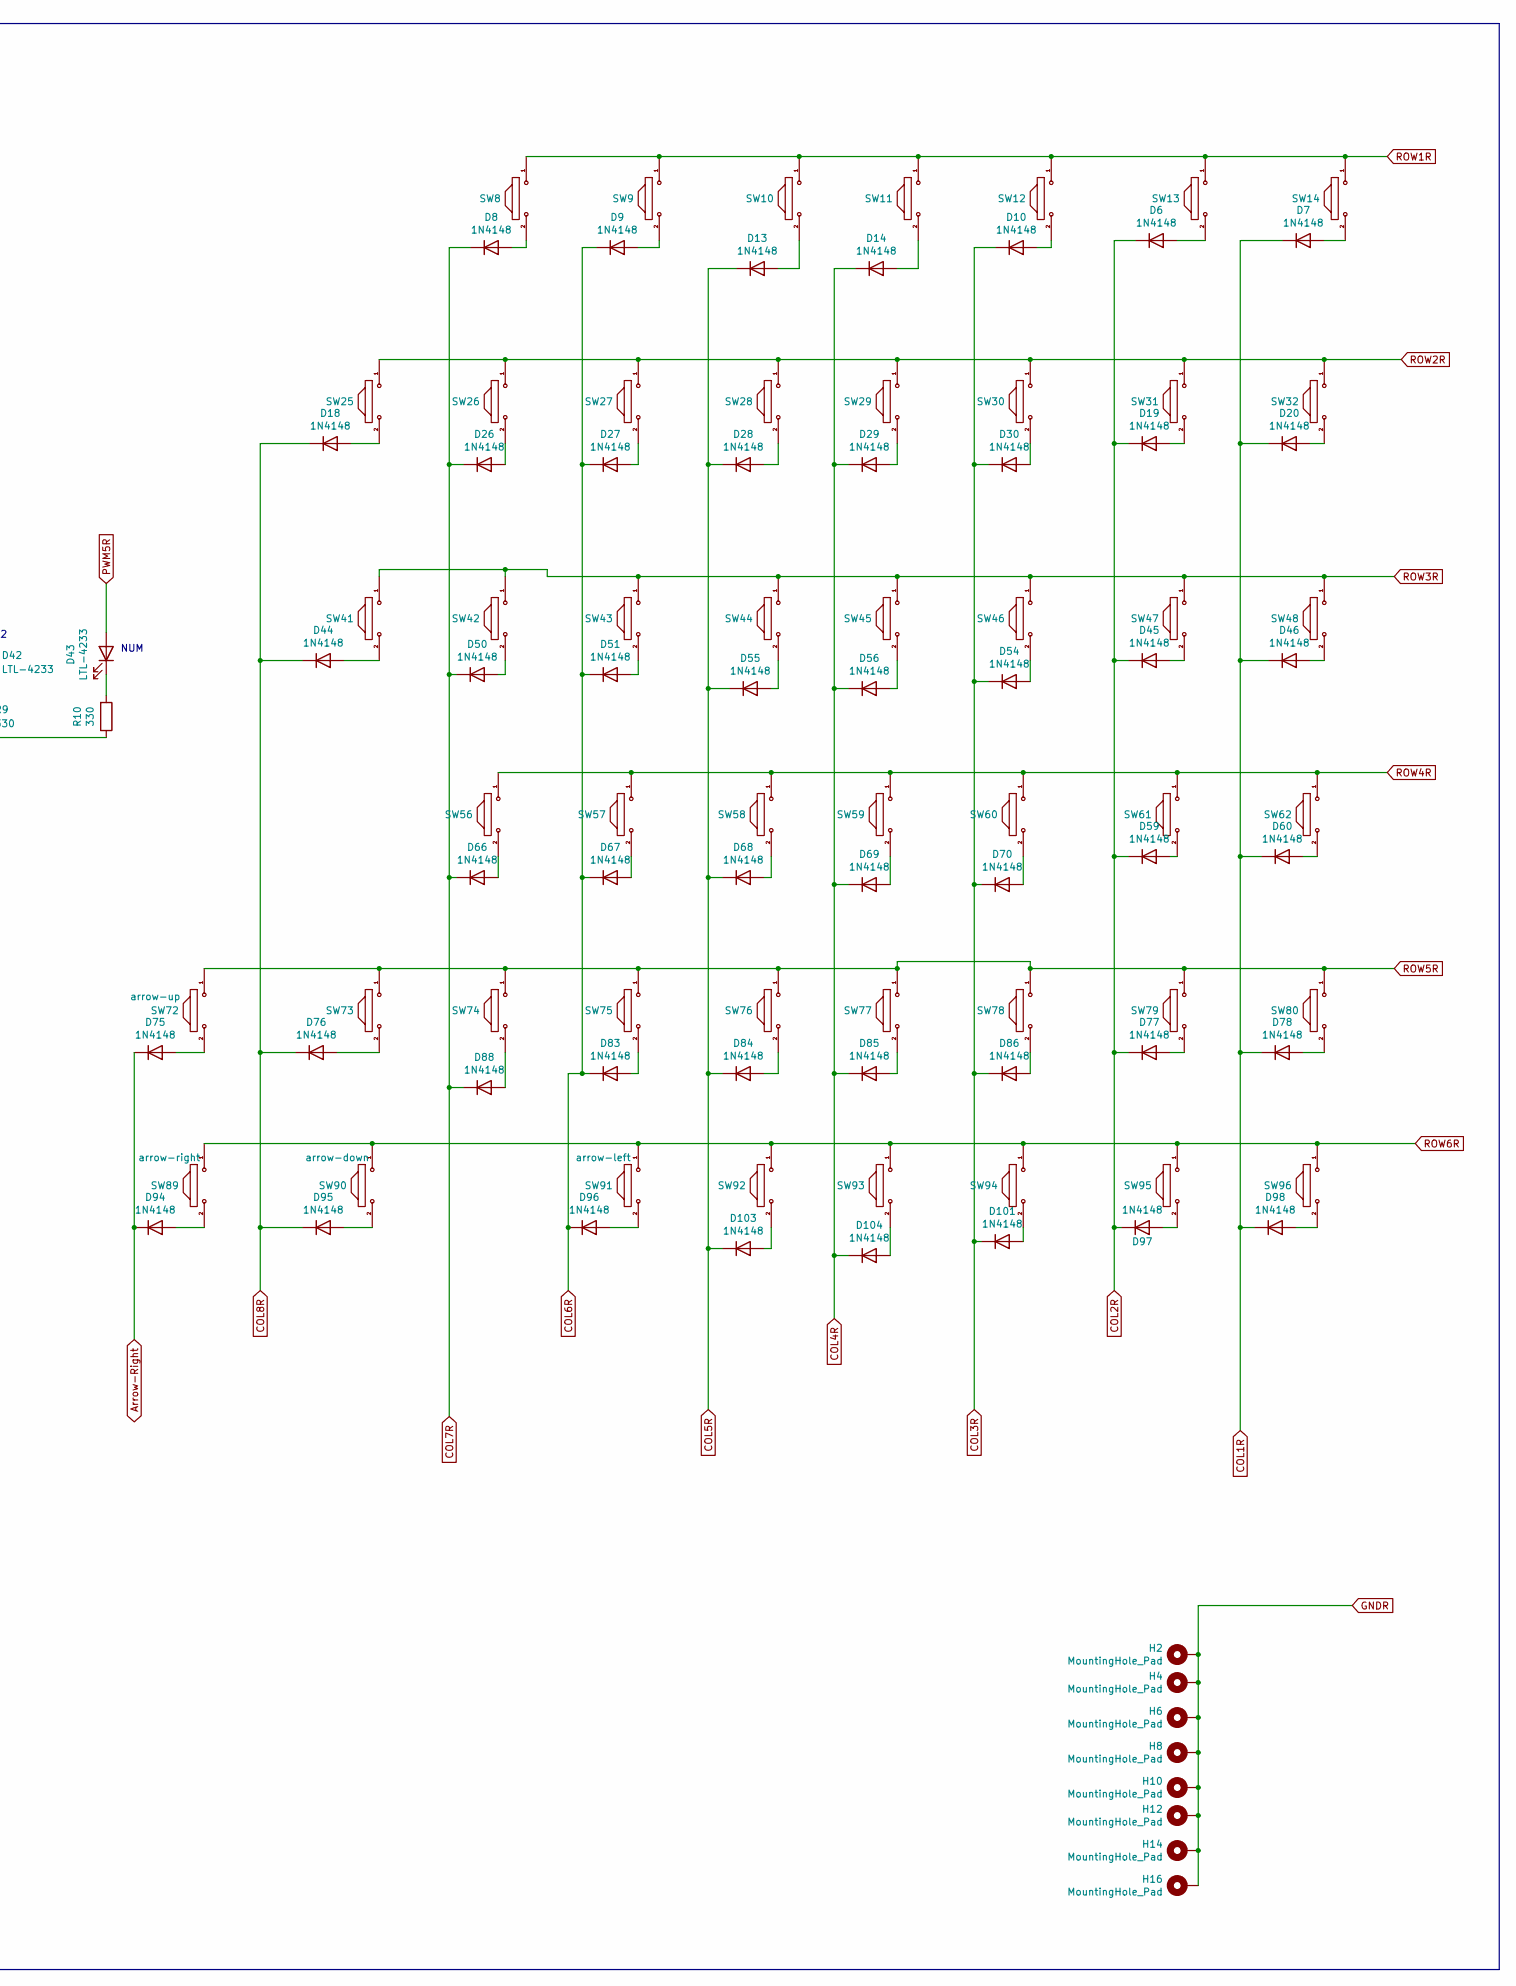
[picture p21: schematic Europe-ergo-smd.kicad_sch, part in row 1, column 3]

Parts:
D1, D2, D3, D4, D5, D6, D7, D8, D9, D10, D11, D12, D13, D14, D15, D16, D17, D18, D19, D20, D21, D22, D23, D24, D25, D26, D27, D28, D29, D30, D33, D34, D35, D44, D45, D46, D47, D48, D49, D50, D51, D52, D53, D54, D55, D56, D57, D58, D59, D60, D61, D62, D63, D64, D65, D66, D67, D68, D69, D70, D71, D72, D73, D74, D75, D76, D77, D78, D79, D80, D81, D82, D83, D84, D85, D86, D87, D88, D89, D90, D91, D92, D93, D94, D95, D96, D97, D98, D99, D100, D101, D102, D103, D104: 1N4148; D_1812_4532Metric
D31, D32, D36, D37, D38, D43: LTL-4233; D_A-405_P2.54mm_Vertical_AnodeUp
D39, D40, D41, D42: LTL-4233; D_DO-34_SOD68_P2.54mm_Vertical_KathodeUp
H1, H2, H3, H4, H5, H6, H7, H8, H9, H10, H11, H12, H13, H14, H15, H16: MountingHole_Pad; MountingHole_4.3mm_M4_DIN965_Pad
J1, J2: SJ-43514; CUI_SJ-43514
R1, R2, R3, R4, R5, R6, R7, R8, R9, R10: 330; R_1812_4532Metric
R11, R12, R13, R14: 4.7K; R_1812_4532Metric
SW1, SW2, SW3, SW4, SW5, SW6, SW7, SW8, SW9, SW10, SW11, SW12, SW13, SW14, SW18, SW19, SW20, SW21, SW22, SW23, SW24, SW25, SW26, SW27, SW28, SW29, SW30, SW31, SW34, SW35, SW36, SW37, SW38, SW39, SW42, SW43, SW44, SW45, SW46, SW47, SW50, SW51, SW52, SW53, SW54, SW55, SW56, SW57, SW58, SW59, SW60, SW61, SW64, SW65, SW66, SW67, SW68, SW69, SW71, SW72, SW74, SW75, SW76, SW77, SW78, SW79, SW81, SW82, SW83, SW84, SW85, SW86, SW87, SW88, SW89, SW90, SW91, SW92, SW93, SW94, SW95, SW96: MX1A-G1NN; SW_Cherry_MX_1.00u_PCB
SW15, SW16: 800SP9B6M2RE; switch_P5.08mm
SW17, SW32, SW33, SW40, SW41, SW48, SW49, SW62, SW63, SW70, SW73, SW80: MX1A-G1NN; SW_Cherry_MX_1.50u_PCB
U1, U2: SC0915; RPi_Pico_SMD_TH

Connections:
/RUN: SW16.1, U2.30 (RUN)
Arrow-Left: D74.1 (K), D93.1 (K), U1.26 (GPIO20)
Arrow-Right: D75.1 (K), D94.1 (K), U2.26 (GPIO20)
COL1: D1.1 (K), D15.1 (K), D33.1 (K), D57.1 (K), D71.1 (K), D89.1 (K), U1.4 (GPIO2)
COL1R: D7.1 (K), D20.1 (K), D46.1 (K), D60.1 (K), D78.1 (K), D98.1 (K), U2.4 (GPIO2)
COL2: D2.1 (K), D16.1 (K), D34.1 (K), D58.1 (K), D72.1 (K), D90.1 (K), U1.5 (GPIO3)
COL2R: D6.1 (K), D19.1 (K), D45.1 (K), D59.1 (K), D77.1 (K), D97.1 (K), U2.5 (GPIO3)
COL3: D3.1 (K), D21.1 (K), D49.1 (K), D64.1 (K), D79.1 (K), D99.1 (K), U1.14 (GPIO10)
COL3R: D10.1 (K), D30.1 (K), D54.1 (K), D70.1 (K), D86.1 (K), D101.1 (K), U2.14 (GPIO10)
COL4: D11.1 (K), D22.1 (K), D52.1 (K), D65.1 (K), D80.1 (K), D102.1 (K), U1.15 (GPIO11)
COL4R: D14.1 (K), D29.1 (K), D56.1 (K), D69.1 (K), D85.1 (K), D104.1 (K), U2.15 (GPIO11)
COL5: D12.1 (K), D23.1 (K), D53.1 (K), D61.1 (K), D81.1 (K), D100.1 (K), U1.16 (GPIO12)
COL5R: D13.1 (K), D28.1 (K), D55.1 (K), D68.1 (K), D84.1 (K), D103.1 (K), U2.16 (GPIO12)
COL6: D4.1 (K), D24.1 (K), D47.1 (K), D62.1 (K), D82.1 (K), D91.1 (K), U1.17 (GPIO13)
COL6R: D9.1 (K), D27.1 (K), D51.1 (K), D67.1 (K), D83.1 (K), D96.1 (K), U2.17 (GPIO13)
COL7: D5.1 (K), D25.1 (K), D48.1 (K), D63.1 (K), D87.1 (K), U1.19 (GPIO14)
COL7R: D8.1 (K), D26.1 (K), D50.1 (K), D66.1 (K), D88.1 (K), U2.19 (GPIO14)
COL8: D17.1 (K), D35.1 (K), D73.1 (K), D92.1 (K), U1.20 (GPIO15)
COL8R: D18.1 (K), D44.1 (K), D76.1 (K), D95.1 (K), U2.20 (GPIO15)
GNDL: H1.1, H3.1, H5.1, H7.1, H9.1, H11.1, H13.1, H15.1, J1.1, R1.1, R2.1, R3.1, R4.1, R5.1, SW15.2, U1.3 (GND), U1.8 (GND), U1.13 (GND), U1.18 (GND), U1.23 (GND), U1.28 (GND), U1.31 (GPIO26_ADC0), U1.33 (AGND), U1.38 (GND), U1.42 (GND)
GNDR: H2.1, H4.1, H6.1, H8.1, H10.1, H12.1, H14.1, H16.1, J2.1, R6.2, R7.2, R8.2, R9.2, R10.1, SW16.2, U2.3 (GND), U2.8 (GND), U2.13 (GND), U2.18 (GND), U2.23 (GND), U2.28 (GND), U2.33 (AGND), U2.38 (GND), U2.42 (GND)
unnamed: D1.2 (A), SW1.2
unnamed: D2.2 (A), SW2.2
unnamed: D3.2 (A), SW3.2
unnamed: D4.2 (A), SW6.2
unnamed: D5.2 (A), SW7.2
unnamed: D6.2 (A), SW13.2
unnamed: D7.2 (A), SW14.2
unnamed: D8.2 (A), SW8.2
unnamed: D9.2 (A), SW9.2
unnamed: D10.2 (A), SW12.2
unnamed: D11.2 (A), SW4.2
unnamed: D12.2 (A), SW5.2
unnamed: D13.2 (A), SW10.2
unnamed: D14.2 (A), SW11.2
unnamed: D15.2 (A), SW17.2
unnamed: D16.2 (A), SW18.2
unnamed: D17.2 (A), SW24.2
unnamed: D18.2 (A), SW25.2
unnamed: D19.2 (A), SW31.2
unnamed: D20.2 (A), SW32.2
unnamed: D21.2 (A), SW19.2
unnamed: D22.2 (A), SW20.2
unnamed: D23.2 (A), SW21.2
unnamed: D24.2 (A), SW22.2
unnamed: D25.2 (A), SW23.2
unnamed: D26.2 (A), SW26.2
unnamed: D27.2 (A), SW27.2
unnamed: D28.2 (A), SW28.2
unnamed: D29.2 (A), SW29.2
unnamed: D30.2 (A), SW30.2
unnamed: D31.1 (K), R1.2
unnamed: D32.1 (K), R2.2
unnamed: D33.2 (A), SW33.2
unnamed: D34.2 (A), SW34.2
unnamed: D35.2 (A), SW40.2
unnamed: D36.1 (K), R3.2
unnamed: D37.1 (K), R4.2
unnamed: D38.1 (K), R5.2
unnamed: D39.1 (K), R6.1
unnamed: D40.1 (K), R7.1
unnamed: D41.1 (K), R8.1
unnamed: D42.1 (K), R9.1
unnamed: D43.1 (K), R10.2
unnamed: D44.2 (A), SW41.2
unnamed: D45.2 (A), SW47.2
unnamed: D46.2 (A), SW48.2
unnamed: D47.2 (A), SW38.2
unnamed: D48.2 (A), SW39.2
unnamed: D49.2 (A), SW35.2
unnamed: D50.2 (A), SW42.2
unnamed: D51.2 (A), SW43.2
unnamed: D52.2 (A), SW36.2
unnamed: D53.2 (A), SW37.2
unnamed: D54.2 (A), SW46.2
unnamed: D55.2 (A), SW44.2
unnamed: D56.2 (A), SW45.2
unnamed: D57.2 (A), SW49.2
unnamed: D58.2 (A), SW50.2
unnamed: D59.2 (A), SW61.2
unnamed: D60.2 (A), SW62.2
unnamed: D61.2 (A), SW53.2
unnamed: D62.2 (A), SW54.2
unnamed: D63.2 (A), SW55.2
unnamed: D64.2 (A), SW51.2
unnamed: D65.2 (A), SW52.2
unnamed: D66.2 (A), SW56.2
unnamed: D67.2 (A), SW57.2
unnamed: D68.2 (A), SW58.2
unnamed: D69.2 (A), SW59.2
unnamed: D70.2 (A), SW60.2
unnamed: D71.2 (A), SW63.2
unnamed: D72.2 (A), SW64.2
unnamed: D73.2 (A), SW70.2
unnamed: D74.2 (A), SW71.2
unnamed: D75.2 (A), SW72.2
unnamed: D76.2 (A), SW73.2
unnamed: D77.2 (A), SW79.2
unnamed: D78.2 (A), SW80.2
unnamed: D79.2 (A), SW65.2
unnamed: D80.2 (A), SW66.2
unnamed: D81.2 (A), SW67.2
unnamed: D82.2 (A), SW68.2
unnamed: D83.2 (A), SW75.2
unnamed: D84.2 (A), SW76.2
unnamed: D85.2 (A), SW77.2
unnamed: D86.2 (A), SW78.2
unnamed: D87.2 (A), SW69.2
unnamed: D88.2 (A), SW74.2
unnamed: D89.2 (A), SW81.2
unnamed: D90.2 (A), SW82.2
unnamed: D91.2 (A), SW86.2
unnamed: D92.2 (A), SW87.2
unnamed: D93.2 (A), SW88.2
unnamed: D94.2 (A), SW89.2
unnamed: D95.2 (A), SW90.2
unnamed: D96.2 (A), SW91.2
unnamed: D97.2 (A), SW95.2
unnamed: D98.2 (A), SW96.2
unnamed: D99.2 (A), SW83.2
unnamed: D100.2 (A), SW85.2
unnamed: D101.2 (A), SW94.2
unnamed: D102.2 (A), SW84.2
unnamed: D103.2 (A), SW92.2
unnamed: D104.2 (A), SW93.2
unnamed: SW15.1, U1.30 (RUN)
PWM1: D31.2 (A), U1.21 (GPIO16)
PWM1R: D42.2 (A), U2.21 (GPIO16)
PWM2: D32.2 (A), U1.22 (GPIO17)
PWM2R: D41.2 (A), U2.22 (GPIO17)
PWM3: D36.2 (A), U1.24 (GPIO18)
PWM3R: D40.2 (A), U2.24 (GPIO18)
PWM4: D37.2 (A), U1.25 (GPIO19)
PWM4R: D39.2 (A), U2.25 (GPIO19)
PWM5: D38.2 (A), U1.29 (GPIO22)
PWM5R: D43.2 (A), U2.29 (GPIO22)
ROW1: SW1.1, SW2.1, SW3.1, SW4.1, SW5.1, SW6.1, SW7.1, U1.6 (GPIO4)
ROW1R: SW8.1, SW9.1, SW10.1, SW11.1, SW12.1, SW13.1, SW14.1, U2.6 (GPIO4)
ROW2: SW17.1, SW18.1, SW19.1, SW20.1, SW21.1, SW22.1, SW23.1, SW24.1, U1.7 (GPIO5)
ROW2R: SW25.1, SW26.1, SW27.1, SW28.1, SW29.1, SW30.1, SW31.1, SW32.1, U2.7 (GPIO5)
ROW3: SW33.1, SW34.1, SW35.1, SW36.1, SW37.1, SW38.1, SW39.1, SW40.1, U1.9 (GPIO6)
ROW3R: SW41.1, SW42.1, SW43.1, SW44.1, SW45.1, SW46.1, SW47.1, SW48.1, U2.9 (GPIO6)
ROW4: SW49.1, SW50.1, SW51.1, SW52.1, SW53.1, SW54.1, SW55.1, U1.10 (GPIO7)
ROW4R: SW56.1, SW57.1, SW58.1, SW59.1, SW60.1, SW61.1, SW62.1, U2.10 (GPIO7)
ROW5: SW63.1, SW64.1, SW65.1, SW66.1, SW67.1, SW68.1, SW69.1, SW70.1, SW71.1, U1.11 (GPIO8)
ROW5R: SW72.1, SW73.1, SW74.1, SW75.1, SW76.1, SW77.1, SW78.1, SW79.1, SW80.1, U2.11 (GPIO8)
ROW6: SW81.1, SW82.1, SW83.1, SW84.1, SW85.1, SW86.1, SW87.1, SW88.1, U1.12 (GPIO9)
ROW6R: SW89.1, SW90.1, SW91.1, SW92.1, SW93.1, SW94.1, SW95.1, SW96.1, U2.12 (GPIO9)
SCL I2C0: J1.3, R14.1, U1.2 (GPIO1)
SDA I2C0: J1.2, R13.1, U1.1 (GPIO0)
VCCL: J1.4, R13.2, R14.2, U1.40 (VBUS)
VCCR: J2.4, R11.2, R12.2, U2.40 (VBUS)
sclR: J2.3, R11.1, U2.2 (GPIO1)
sdaR: J2.2, R12.1, U2.1 (GPIO0)

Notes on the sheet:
EG2614-ND
Keyswitch Hotswap sockets: 0305-2-15-80-47-80-10-0 or Digikey: ED90584-ND
CAPS
Scroll
OMIT 4.7K RES IF SERIAL COMM IS USED.
SPLIT_HAND_PIN_LOW_IS_LEFT
NUM
TRRS jack, SJ-43514

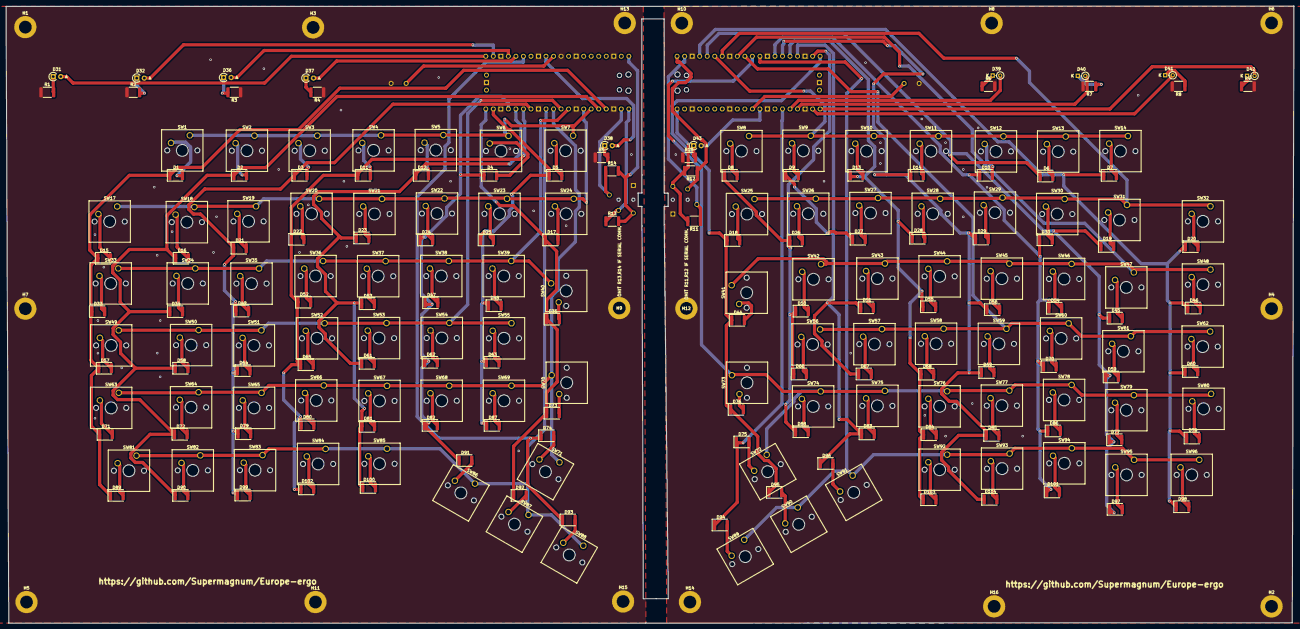
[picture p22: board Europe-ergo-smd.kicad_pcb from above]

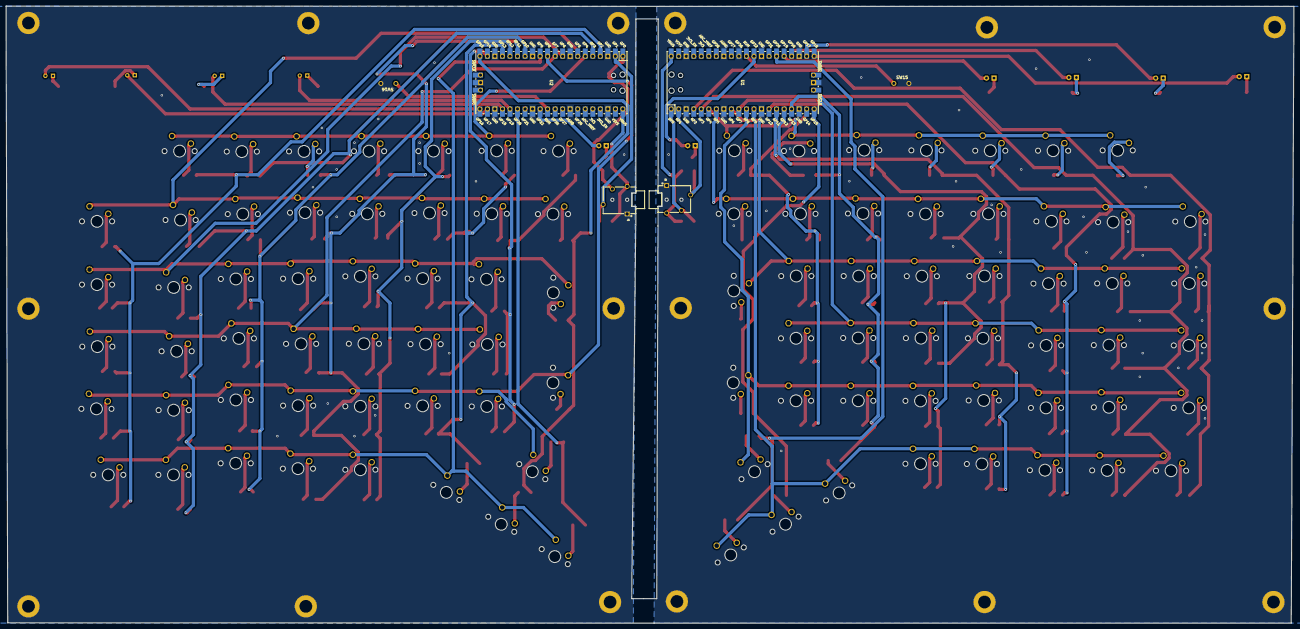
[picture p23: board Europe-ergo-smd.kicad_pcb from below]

Board: 2 copper layers, 434.5 x 208.2 mm, 234 parts (6 on the bottom side), 154 nets.

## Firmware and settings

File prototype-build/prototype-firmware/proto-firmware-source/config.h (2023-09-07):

// Copyright 2023 Supermagnum (@Supermagnum)
// SPDX-License-Identifier: GPL-2.0-or-later

#pragma once

/*
 * Feature disable options
 *  These options are also useful to firmware size reduction.
 */

/* disable debug print */
//#define NO_DEBUG

/* disable print */
//#define NO_PRINT

/* disable action features */
//#define NO_ACTION_LAYER
//#define NO_ACTION_TAPPING
//#define NO_ACTION_ONESHOT
#define SPLIT_LAYER_STATE_ENABLE
#define SPLIT_HAND_MATRIX_GRID GP27, GP26

/* split configuration */
#define SERIAL_USART_FULL_DUPLEX    // Enable full duplex operation mode

#define SERIAL_USART_TX_PIN GP0     // USART TX pin
#define SERIAL_USART_RX_PIN GP1     // USART RX pin
#define SERIAL_USART_PIN_SWAP       // Swap TX and RX pins if keyboard is master halve. (Only available on some MCUs)

#define SPLIT_LED_STATE_ENABLE      // Sync lock LED status between halves

#define LED_CAPS_LOCK_PIN GP16 	//The pin that controls the Caps Lock LED
#define LED_SCROLL_LOCK_PIN GP17 	//The pin that controls the Scroll Lock LED


#define LED_PIN_ON_STATE 1 	//The state of the indicator pins when the LED is "on" - 1 for high, 0 for low
#define LED1_PIN GP18 //PWM3 L1 LED
#define LED2_PIN GP19 //PWM4 L2 LED
#define LED3_PIN GP22 //Controls NUM layer LED on or off, PWM5

#define DEBOUNCE 9

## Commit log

2022-12-05 Add files via upload
    upload because of name change.
    [Europe-ergo-B_Cu.gbr, Europe-ergo-B_Mask.gbr, Europe-ergo-B_Paste.gbr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]
2022-12-05 Add files via upload
    fixed some naming errors.
    [config.h]
2022-12-05 Add files via upload
    Moved the MCU and reset switch to the reverse side of the pcb.
    [Europe-ergo-B_Cu.gbr, Europe-ergo-B_Mask.gbr, Europe-ergo-B_Paste.gbr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]
2022-12-05 Add files via upload
    updated stl files.
    [Europe-ergo-top-plate.stl, box1.stl, box2.stl]
2022-12-09 Add files via upload
    updated files
    [Europe-ergo-B_Cu.gbr, Europe-ergo-B_Mask.gbr, Europe-ergo-B_Paste.gbr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]
2022-12-09 Add files via upload
    Fixed some small issues
    [Europe-ergo-top-plate.stl, Europe-ergo-top-plate2.stl, Europe-ergo.FCStd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]
2022-12-09 Update BOM.txt
    updated parts list.
2023-01-15 Add files via upload
    small fix
    [Europe-ergo-B_Cu.gbr, Europe-ergo-B_Mask.gbr, Europe-ergo-B_Paste.gbr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]
2023-02-16 Add files via upload
    Moved switches footprints closer.
    [Europe-ergo-B_Cu.gbr, Europe-ergo-B_Mask.gbr, Europe-ergo-B_Paste.gbr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]
2023-03-02 Add files via upload
    added freecad file and stl files.
    [Europe-ergo-left.stl, Europe-ergo-right.stl, Europe-ergo.FCStd]
2023-03-23 Add files via upload
    Added a default keymap file that implements the NUM layer, and controls the relevant LED.
2023-05-24 Add files via upload
    update
    [Europe-ergo-boxes.stl, Europe-ergo-left.stl, Europe-ergo-right.stl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]
2023-06-28 added prototype picture
2023-07-07 Update config.h
    Added options for proper PCB.
2023-07-12 Added debug information
    Issues are at row 5, 10 and 11. These prints wrong characters.
2023-07-25 Update keymap.c
    added LED initialization
2023-08-10 Add files via upload
    Pictures from prototype build process.
